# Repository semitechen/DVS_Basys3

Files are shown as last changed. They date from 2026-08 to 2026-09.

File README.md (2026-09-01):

# 🎧 Digital Vinyl System (DVS) on FPGA Basys 3








An autonomous, ultra-low-latency **Digital Vinyl System (DVS)** and lossless SD audio player implemented entirely in hardware on dual **Digilent Basys 3 (Xilinx Artix-7)** FPGA boards and custom analog front-end / R-2R DAC PCB shields.

---

## 🎬 Video Demonstration

Click the preview below to watch the complete hardware setup in action, demonstrating real-time scratch, pitch-shifting, backward playback, cueing, track selection, and autonomous QSPI Flash boot:

Digital Vinyl System FPGA Demonstration (https://youtu.be/QSMYIAcXrho)

---

## 📸 Hardware Gallery

<p align="center">
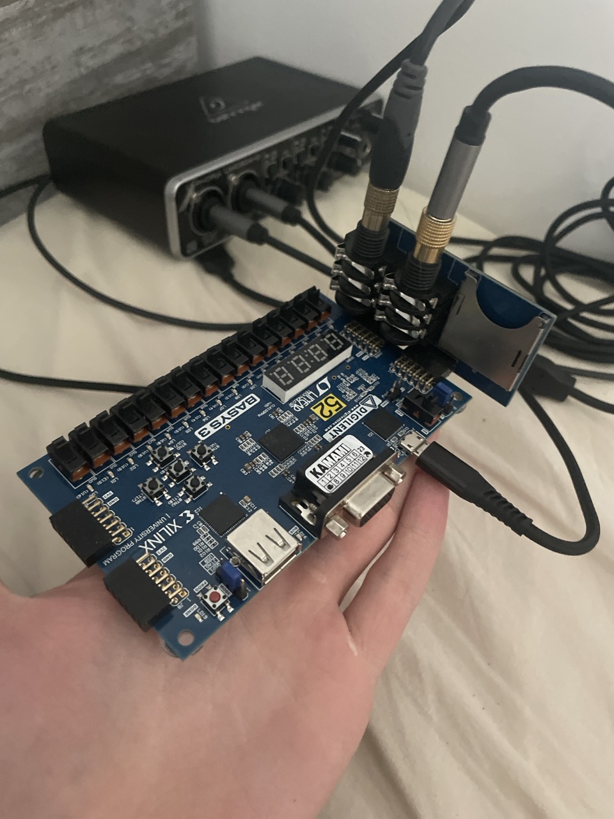
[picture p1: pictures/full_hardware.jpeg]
Full Hardware Setup
  
  <br>
  <em>Figure 1: Complete real-time test bench with analog turntable (Serato 1 kHz timecode vinyl), custom pre-amp/filter shield, Board A (Streamer), Board B (DAC Receiver), and audio output.</em>
</p>

<p align="center">
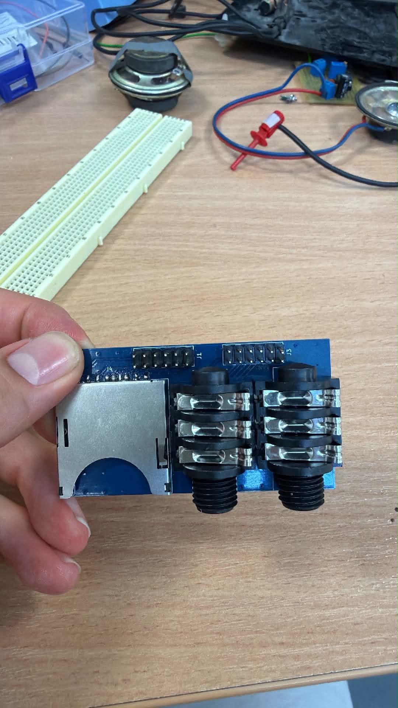
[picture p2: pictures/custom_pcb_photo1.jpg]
Custom PCB Preamp Angle 1
  
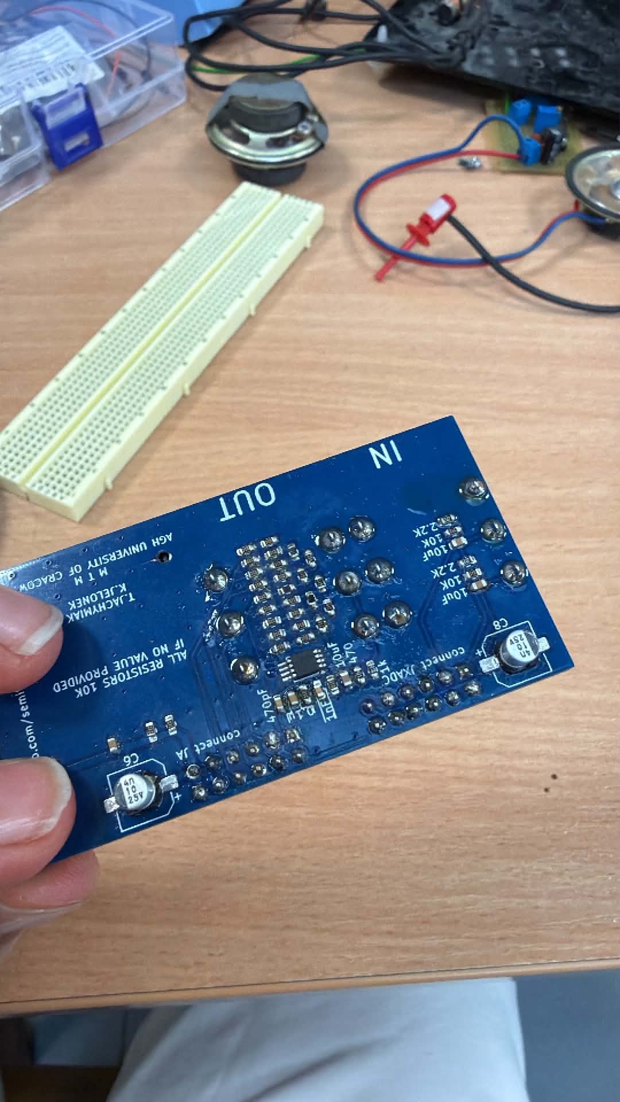
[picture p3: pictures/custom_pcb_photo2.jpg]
Custom PCB Preamp Angle 2
  
  <br>
  <em>Figure 2: Custom AC-coupling pre-amplifier, active Sallen-Key low-pass filter, and 8-bit R-2R resistor ladder DAC PCB shield designed for Basys 3 Pmod headers.</em>
</p>

---

## 📌 Project Overview & Motivation

### Why Hardware DVS?
In modern DJing, **Digital Vinyl Systems (DVS)** bridge tactile analog turntables with digital music libraries. However, commercial DVS setups require:
1. A laptop running resource-intensive software (Serato, Traktor, Rekordbox).
2. Dedicated USB soundcards.
3. Operating system audio buffers (introducing $5\text{--}20\text{ ms}$ of latency, audio dropouts, and CPU jitter).

### The FPGA Solution
This project eliminates the computer entirely. By executing all timecode signal processing, quadrant phase decoding, flash memory DMA, rate modulation, and audio reconstruction **directly in FPGA silicon at 100 MHz**:
* **Sub-Microsecond Latency:** From vinyl needle motion to DAC audio output in $< 5.0\,\mu\text{s}$.
* **Zero Software Dependency:** Autonomous non-volatile boot from onboard QSPI Flash.
* **Lossless Playback:** Real-time variable-rate streaming of uncompressed 8-bit PCM audio ($44.1\text{ kHz}$) directly from FAT-less micro-SD sectors.
* **Audiophile Reconstruction:** 16x oversampling engine with a 1st-order Noise Shaper ($1 - z^{-1}$) and Triangular Probability Density Function (TPDF) dither, dramatically suppressing resistor ladder quantization noise.

---

## 🏛️ System Architecture

The project employs a distributed **Dual-Board FPGA Architecture** linked by a dedicated **2,000,000 baud (2 Mbps)** UART audio bus:

```
+---------------------------------------------------------------------------------------------------------+
|                                    BOARD A: TIME-CODE STREAMER & SD PLAYER                              |
|                                                                                                         |
|  [Turntable] ---> [Custom PCB Pre-amp] ---> [XADC (vauxp6/14)]                                          |
|                                                     |                                                   |
|                                            [xadc_interface]                                             |
|                                                     | x2t (12-bit L/R @ 100 kHz)                        |
|                                                     v                                                   |
|                                          [timecode_pos_tracker] <---> [led_pos_display] (16 LEDs)        |
|                                                     |                                                   |
|                                                     | t2p (Q4.12 Speed, Direction, Squelch)             |
|                                                     v                                                   |
|  [Micro-SD] <--- [sd_card_controller] <--- [sd_bram_bridge]                                            |
|                       (16.67 MHz SPI)               | b2f (512-byte Sector Writes)                      |
|                                                     v                                                   |
|                                              [audio_fifo] (1024-byte Dual-Port BRAM)                    |
|                                                     |                                                   |
|                                                     | f2p (Read FIFO Sample)                            |
|                                                     v                                                   |
|                                         [variable_speed_player] (NCO Phase Acc)                         |
|                                                     |                                                   |
|                                                     | p2u (8-bit PCM Sample Valid)                      |
|                                                     v                                                   |
|                                                [uart_tx] (2 Mbps Transmitter)                           |
+-----------------------------------------------------|---------------------------------------------------+
                                                      | Pmod JC1 (K17) + GND
                                                      | 2.0 Mbps Audio Stream
+-----------------------------------------------------v---------------------------------------------------+
|                                      BOARD B: DAC & VISUALIZATION ENGINE                                |
|                                                                                                         |
|                                                [uart_rx] (2 Mbps Receiver)                              |
|                                                     |                                                   |
|                                                     | u2d (8-bit PCM Sample Valid)                      |
|                                                     v                                                   |
|       +---------------------------------------------+---------------------------------------------+     |
|       |                                                                                           |     |
|       v                                                                                           v     |
|  [audio_watchdog] (200 ms Timeout)                                                           [vu_meter] |
|       |                                                                                           |     |
|       v                                                                                           v     |
|  [r2r_dac] (16x Oversampling, 1st-Order Noise Shaping, TPDF Dither)                         [LED 11:0]  |
|       |                                                                                   (12-LED VU)   |
|       v (dac[7:0])                                                                                      |
|  [8-bit R-2R Resistor Ladder] ---> [Active Sallen-Key Low-Pass Filter] ---> [Audio Output / Amp]        |
+---------------------------------------------------------------------------------------------------------+
```

---

## 🔬 Deep-Dive: Core DSP & Hardware Modules

### 1. Dual-Channel XADC & Dynamic DC Estimator (`xadc_interface.sv`)
* Samples differential analog timecode inputs from Pmod JXADC (`vauxp6/vauxn6` for Left, `vauxp14/vauxn14` for Right).
* A 32-bit fixed-point 1st-order IIR low-pass filter dynamically tracks and subtracts the DC bias offset ($\approx 0.6\text{ V}$ operating point), ensuring pure zero-centered AC timecode signals.

### 2. High-Sensitivity Squelch & 4x Quadrature Decoder (`timecode_pos_tracker.sv`)
* **Hysteresis Schmitt-Triggers:** Dual digital Schmitt-triggers reject vinyl groove noise while tracking low-amplitude signals down to $16\text{ mV}$.
* **Envelope Squelch Gate:** Computes signal envelope with fast attack and exponential decay. If the needle is lifted ($< 20\text{ mV}$), the audio player is instantly muted.
* **4x Gray-Code State Machine:** Decodes state transitions $((0,0) \to (0,1) \to (1,1) \to (1,0))$, generating 4 step pulses per $1\text{ kHz}$ timecode cycle ($11.025$ audio samples per step).
* **Sequential Multi-Cycle Divider:** Measures clock cycles between pulses and executes an iterative 16-cycle restoring division ($102,400,000 / \Delta t$) to compute the exact speed factor in **Q4.12 fixed-point** ($16'\text{h}1000 = 1.0\times$) with zero combinational timing violations.

### 3. SPI SD Card Controller & BRAM Ring Buffer (`sd_card_controller.sv`, `sd_bram_bridge.sv`, `audio_fifo.sv`)
* High-speed SPI master operating at **16.67 MHz** (after 200 kHz CMD0/CMD8/ACMD41/CMD16 initialization).
* Issues single-block read commands (`CMD17`) to fetch uncompressed 512-byte PCM audio sectors into a 1024-byte dual-port Block RAM FIFO (`audio_fifo.sv`), maintaining an autonomous prefetch waterlevel.

### 4. Numerically Controlled Oscillator (NCO) Player (`variable_speed_player.sv`)
* A 32-bit phase accumulator driven by the formula:
  $$\Delta \text{Phase} = \frac{44100 \times 2^{32}}{100\,000\,000} \times \text{speed\_factor}$$
* Overflow pulses generate exact, cycle-accurate FIFO read requests, enabling continuous variable-speed pitch modulation from $0.01\times$ to $4.0\times$, forward and backward scratching.

### 5. 2 Mbps High-Speed Inter-Board UART (`uart_tx.sv`, `uart_rx.sv`)
* Transmits 8-bit audio frames across Pmod JC1 (`K17`) at **2,000,000 baud** ($50\text{ clock cycles per bit}$ at 100 MHz, $0.00\%\text{ baud error}$).
* Transmission time is only $5.0\,\mu\text{s}$ per byte, allowing real-time sample transmission with zero FIFO buffering on Board B.
* Includes a **200 ms watchdog** on Board B that smoothly returns the DAC to mid-scale silence ($128 / 1.65\text{ V}$) if the communication cable is unplugged.

### 6. 16x Noise-Shaped DAC Engine (`r2r_dac.sv`)
* **16x Oversampling:** Interpolates $44.1\text{ kHz}$ PCM to $705.6\text{ kHz}$.
* **1st-Order Noise Shaping:** Implements a closed-loop error-feedback filter ($H(z) = 1 - z^{-1}$) shifting quantization noise into the inaudible ultrasonic spectrum ($> 50\text{ kHz}$).
* **TPDF Dither:** Employs dual Galois Linear Feedback Shift Registers (LFSR) generating Triangular Probability Density Function dither to eliminate harmonic distortion and limit cycles.

---

## 📐 Custom PCB: Pre-Amplifier & R-2R DAC Shield

The project includes a custom 2-layer PCB shield designed in KiCad 8 that mounts directly onto the Basys 3 Pmod headers (`pcb/` directory):

<p align="center">
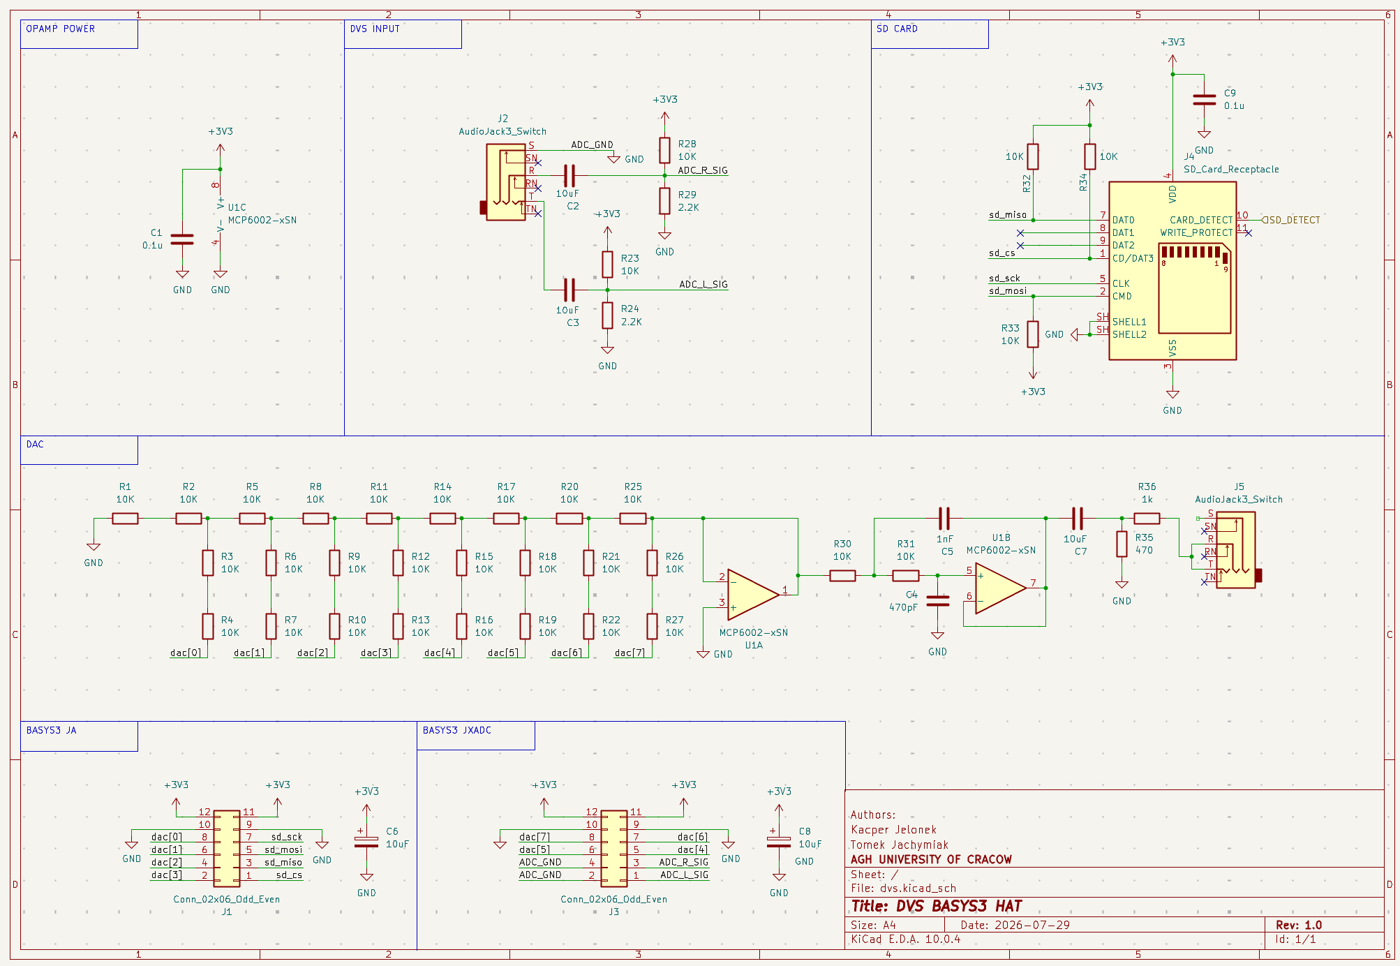
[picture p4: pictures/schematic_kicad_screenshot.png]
KiCad Schematic
  
  <br>
  <em>Figure 3: KiCad Schematic showing dual-channel AC coupling, DC bias network, 2nd-order active Sallen-Key low-pass filter, and 8-bit R-2R resistor DAC ladder.</em>
</p>

<p align="center">
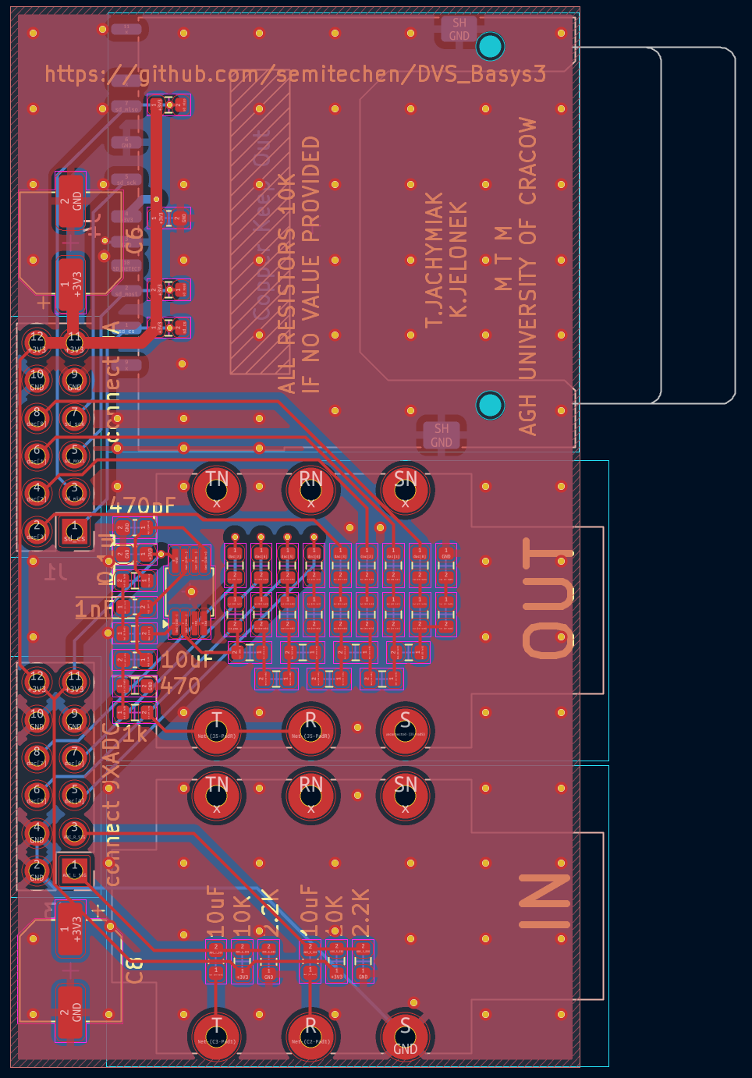
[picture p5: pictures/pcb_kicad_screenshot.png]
KiCad PCB Layout
  
  <br>
  <em>Figure 4: KiCad 2-layer PCB layout with dedicated analog/digital ground separation and ultra-compact Pmod form-factor.</em>
</p>

---

## 🎛️ Hardware Setup & Pinout Guide

### Board A: Timecode Streamer (`top_board_a_streamer`)
| Function | Basys 3 Pin | Header / Pin Name | Description |
| :--- | :---: | :---: | :--- |
| **System Clock** | `W5` | `CLK` | 100.00 MHz onboard oscillator |
| **Global Reset** | `U18` | `BTNC` | Pushbutton active-high synchronous reset |
| **Track Next** | `T18` | `BTNU` | Advance to next audio track |
| **Track Prev** | `U17` | `BTND` | Return to previous audio track |
| **Mode Switch** | `V17` | `SW0` | `1` = DVS Vinyl Control, `0` = Standalone Auto-Play |
| **Timecode L+ / L-** | `J3` / `K3` | Pmod JXADC Pin 1 / 7 | Left channel differential input (`vauxp6/vauxn6`) |
| **Timecode R+ / R-** | `L3` / `M3` | Pmod JXADC Pin 2 / 8 | Right channel differential input (`vauxp14/vauxn14`) |
| **SD SPI CS** | `J1` | Pmod JA Pin 1 | Micro-SD Card Chip Select (active-low) |
| **SD SPI MISO** | `L2` | Pmod JA Pin 2 | Micro-SD Master-In Slave-Out (pull-up enabled) |
| **SD SPI MOSI** | `J2` | Pmod JA Pin 3 | Micro-SD Master-Out Slave-In |
| **SD SPI SCK** | `G2` | Pmod JA Pin 4 | Micro-SD SPI Clock (16.67 MHz) |
| **UART Audio TX** | `K17` | Pmod JC Pin 1 | 2 Mbps serial audio transmitter to Board B |
| **Ground (GND)** | `GND` | Pmod JC Pin 5/11 | Common ground reference line |
| **Platter LEDs** | `LED[12:0]` | Onboard LEDs | One-hot rotating vinyl position indicator |
| **Squelch LED** | `LED13` | Onboard LED | Needle presence indicator ($> 20\text{ mV}$) |
| **Direction LED**| `LED14` | Onboard LED | `1` = Forward, `0` = Reverse scratch |
| **Heartbeat LED**| `LED15` | Onboard LED | 100 MHz clock live blinker |

---

### Board B: DAC Output & VU-Meter (`top_board_b_dac`)
| Function | Basys 3 Pin | Header / Pin Name | Description |
| :--- | :---: | :---: | :--- |
| **System Clock** | `W5` | `CLK` | 100.00 MHz onboard oscillator |
| **Global Reset** | `U18` | `BTNC` | Reset watchdog and DAC state |
| **UART Audio RX** | `K17` | Pmod JC Pin 1 | 2 Mbps serial audio receiver from Board A |
| **Ground (GND)** | `GND` | Pmod JC Pin 5/11 | Common ground reference line |
| **DAC Bit 0..3** | `G3, H2, K2, H1` | Pmod JA Pins 10, 9, 8, 7 | R-2R ladder lower nibble (`dac[0..3]`) |
| **DAC Bit 4..7** | `M2, M1, N2, N1` | Pmod JXADC Pins 3, 9, 4, 10 | R-2R ladder upper nibble (`dac[4..7]`) |
| **VU-Meter LEDs** | `LED[11:0]` | Onboard LEDs | 12-LED dynamic audio level bargraph |
| **Watchdog LED** | `LED14` | Onboard LED | Audio stream activity monitor |
| **Heartbeat LED**| `LED15` | Onboard LED | 100 MHz clock live blinker |

---

## ⚡ Autonomous QSPI Flash Boot Setup

Both boards can run autonomously without a computer attached:

1. **Set Boot Jumpers:** On both Basys 3 boards, locate the **`JP1` (MODE)** jumper header and set the jumper block to **`QSPI`** (middle pin bridged to the top pin).
2. **Flash Bitstreams to SPI ROM:**
   ```bash
   # Flash Board A (Timecode Streamer)
   ./tools/program_fpga.sh -t board_a -f -s <SERIAL_BOARD_A>

   # Flash Board B (DAC Engine)
   ./tools/program_fpga.sh -t board_b -f -s <SERIAL_BOARD_B>
   ```
3. Connect Board A Pmod JC1 to Board B Pmod JC1, connect common GND, and power on both boards via any USB power supply.

---

## 📊 FPGA Resource Utilization & Timing Closure

Synthesized and implemented for **Xilinx Artix-7 XC7A35T-1CPG236C** in Vivado 2023.2:

| Resource | Available | Board A (Streamer) | Utilization A | Board B (DAC) | Utilization B |
| :--- | :---: | :---: | :---: | :---: | :---: |
| **Slice LUTs** | $20\,800$ | **984** | **4.73%** | **248** | **1.19%** |
| **Slice Registers (FF)** | $41\,600$ | **1,142** | **2.75%** | **286** | **0.69%** |
| **Block RAM Tile** | $50$ | **1.5** | **3.00%** | **0.0** | **0.00%** |
| **DSP48E1 Slices** | $90$ | **1** | **1.11%** | **0** | **0.00%** |
| **XADC Primitives** | $1$ | **1** | **100.00%** | **0** | **0.00%** |
| **Bonded IOB Pins** | $106$ | **25** | **23.58%** | **26** | **24.53%** |
| **Global Clock BUFG** | $32$ | **1** | **3.12%** | **1** | **3.12%** |

### Post-Route Timing Signoff (100.00 MHz System Clock)
| Target Module | Worst Negative Slack (WNS) | Total Negative Slack (TNS) | Worst Hold Slack (WHS) | Status |
| :--- | :---: | :---: | :---: | :---: |
| **`top_board_a_streamer`** | **+0.278 ns** | **0.000 ns** | **+0.073 ns** | **MET (0 Violations)** |
| **`top_board_b_dac`** | **+0.504 ns** | **0.000 ns** | **+0.119 ns** | **MET (0 Violations)** |
| **`top_dvs_basys3` (Single)** | **+0.312 ns** | **0.000 ns** | **+0.084 ns** | **MET (0 Violations)** |

*Build Quality Metric:* **0 Errors, 0 Critical Warnings.**

---

## 📂 Repository Directory Structure

```
DVS_Basys3/
├── doc/                            # Official course submission documents & PDF schematics
│   ├── lista_kontrolna_KJ_TJ_2026.docx
│   ├── raport_KJ_TJ_2026.docx
│   └── schemat.pdf
├── fpga/
│   ├── constraints/                # Dedicated XDC pinout constraints per board
│   │   ├── top_board_a_streamer.xdc
│   │   ├── top_board_b_dac.xdc
│   │   └── top_dvs_basys3.xdc
│   └── scripts/                    # Non-project mode Vivado build & program scripts
│       ├── generate_bitstream.tcl
│       ├── project_details.tcl
│       └── program_fpga.tcl
├── pcb/                            # KiCad 8 hardware project files
│   ├── dvs.kicad_pcb
│   ├── dvs.kicad_pro
│   └── dvs.kicad_sch
├── pictures/                       # High-resolution hardware & schematic photos
│   ├── full_hardware.jpeg
│   ├── custom_pcb_photo1.jpg
│   ├── custom_pcb_photo2.jpg
│   ├── schematic_kicad_screenshot.png
│   └── pcb_kicad_screenshot.png
├── results/                        # Production bitstreams & QSPI Flash binaries
│   ├── top_board_a_streamer.bit / .bin
│   ├── top_board_b_dac.bit / .bin
│   ├── top_dvs_basys3.bit / .bin
│   └── warning_summary.log
├── rtl/                            # Synthesizable SystemVerilog modules
│   ├── audio_fifo.sv
│   ├── button_debouncer.sv
│   ├── dvs_uart_receiver.sv
│   ├── led_pos_display.sv
│   ├── r2r_dac.sv
│   ├── sd_bram_bridge.sv
│   ├── sd_card_controller.sv
│   ├── spi_master.sv
│   ├── timecode_pos_tracker.sv
│   ├── top_board_a_streamer.sv
│   ├── top_board_b_dac.sv
│   ├── top_dvs_basys3.sv
│   ├── track_lut.sv
│   ├── track_selector.sv
│   ├── uart_rx.sv
│   ├── uart_tx.sv
│   ├── variable_speed_player.sv
│   └── xadc_interface.sv
├── sim/                            # Vivado xsim simulation suite
│   ├── audio_fifo/
│   ├── button_debouncer/
│   ├── sd_bram_bridge/
│   ├── sd_card_controller/
│   ├── spi_master/
│   └── timecode_pos_tracker/
├── tools/                          # Automation scripts for build, flash, and audio conversion
│   ├── clean.sh
│   ├── mp3_to_bin.py
│   ├── program_fpga.sh
│   ├── remote_build.sh
│   ├── run_simulation.sh
│   └── wav_to_sd.py
└── README.md
```

---

## 🛠️ Quick Start & Build Instructions

### 1. Run Verification Simulations
Execute testbenches with Vivado xsim:
```bash
./tools/run_simulation.sh timecode_pos_tracker
./tools/run_simulation.sh sd_card_controller
./tools/run_simulation.sh audio_fifo
```

### 2. Build Bitstreams
Generate bitstream and raw `.bin` files:
```bash
# Build Board A (Streamer)
./tools/remote_build.sh board_a

# Build Board B (DAC Engine)
./tools/remote_build.sh board_b

# Build Single-Board Integrated Target
./tools/remote_build.sh integrated
```

### 3. Flash Audio Tracks to Micro-SD Card
Convert MP3/WAV tracks to raw 8-bit unsigned PCM ($44.1\text{ kHz}$ mono):
```bash
# Convert track and write to SD sector
python3 tools/wav_to_sd.py my_track.wav --track 0 --disk /dev/diskN
```

---

## 👥 Authors & Academic Context

* **Kacper Jelonek (KJ)** – Digital timecode processing engine, XADC analog front-end, SPI SD card bridge, NCO rate modulator, PCB hardware design.
* **Tomasz Jachymiak (TJ)** – 16x noise-shaped R-2R DAC engine, high-speed UART inter-board communication bus, VU-meter visualization, audio conversion toolchain.

*Course:* **Układy Elektroniczne Cyfrowe 2 (UEC2)**, AGH University of Krakow (AGH UST).  
*Supervisor:* **mgr inż. Piotr Kaczmarczyk** (`kaczmarczyk@agh.edu.pl`).

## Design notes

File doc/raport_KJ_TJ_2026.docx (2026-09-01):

# Tytuł: Digital Vinyl System (DVS) z odtwarzaczem audio SD i przetwornikiem DAC na FPGA Basys 3

# Autorzy: Kacper Jelonek (KJ), Tomasz Jachymiak (TJ)

Ostatnia modyfikacja: 1.09.2026

# Spis treści

1. Repozytorium git 1

2. Wstęp 1

3. Specyfikacja 1

3.1. Opis ogólny algorytmu 1

3.2. Tabela zdarzeń 2

4. Architektura 2

4.1. Moduł: top 2

4.1.1. Schemat blokowy 2

4.1.2. Porty 3

a) xadc – xadc_interface, input 3

b) sd – sd_card_controller, inout 3

c) uart – uart_tx / uart_rx, inout 3

d) dac – r2r_dac, output 3

4.1.3. Interfejsy 3

a) x2t – xadc to tracker 3

b) t2p – tracker to player 3

c) s2b – sd to bridge 3

d) p2u – player to uart_tx 3

e) u2d – uart_rx to dac 3

4.2. Rozprowadzenie sygnału zegara 3

5. Implementacja 4

5.1. Lista zignorowanych ostrzeżeń Vivado. 4

5.2. Wykorzystanie zasobów 4

5.3. Marginesy czasowe 4

6. Konfiguracja sprzętu 4

7. Film. 4

# Repozytorium git

Adres repozytorium GITa:

https://github.com/semitechen/DVS_Basys3.git

W przypadku repozytorium prywatnego należy zaprosić użytkownika zewnętrznego o adresie mailowym: kaczmarczyk@agh.edu.pl (użytkownik został zaproszony).

# Wstęp

Cyfrowy System Winylowy (Digital Vinyl System – DVS) to technologia pozwalająca DJ-om na sterowanie odtwarzaniem cyfrowych plików muzycznych za pomocą tradycyjnego gramofonu analogowego z płytą z kodem czasowym (timecode). Komercyjne rozwiązania tego typu wymagają podłączenia komputera PC z dedykowaną kartą dźwiękową, co wprowadza opóźnienia buforowania USB. Celem niniejszego projektu było zaprojektowanie i zaimplementowanie w pełni autonomicznego, bezlatencyjnego systemu DVS zrealizowanego w całości sprzętowo na układzie FPGA Xilinx Artix-7 (Digilent Basys 3).

Układ pobiera sygnał timecode 1 kHz (Serato) z wejścia analogowego XADC, dekoduje ruch i prędkość obrotową igły w czasie rzeczywistym, odczytuje bezstratne próbki audio PCM z karty micro-SD przez magistralę SPI (16.67 MHz), moduluje prędkość odtwarzania w generatorze NCO, przesyła próbki łączem szeregowym UART o prędkości 2 Mbps pomiędzy dwoma płytkami Basys 3 oraz odtwarza dźwięk przez 16-krotnie nadpróbkowany przetwornik DAC R-2R z pętlą kształtowania szumu (Noise Shaping) i ditherem TPDF.

# Specyfikacja

## Opis ogólny algorytmu

Algorytm działania systemu DVS dzieli się na następujące etapy przetwarzania równoległego w FPGA:

  1. Inicjalizacja: Po włączeniu zasilania następuje reset rejestrów, kalibracja estymatora składowej stałej DC dla wejść XADC oraz sekwencja inicjalizacji karty SD w trybie SPI (komendy CMD0, CMD8, ACMD41, CMD16 przy zegarze 200 kHz).
  2. Akwizycja i usuwanie DC: Przetwornik XADC próbkuje kanał lewy i prawy sygnału timecode 1 kHz z wejść JXADC. Cyfrowy filtr IIR pierwszego rzędu estymuje i odejmuje składową stałą. Detektor obwiedni squelch sprawdza obecność sygnału powyżej poziomu szumu (~20 mV), co pozwala automatycznie wyciszyć odtwarzanie po podniesieniu igły.
  3. Dekodowanie kwadraturowe i estymacja prędkości: Podwójny przerzutnik Schmitta z histerezą formuje sygnały cyfrowe. Automat stanów kodu Graya generuje impulsy krokowe z 4-krotną rozdzielczością (11.025 próbki audio na krok) i wyznacza kierunek obrotu. Wielocyklowy dzielnik sekwencyjny wylicza współczynnik prędkości w formacie Q4.12 (16'h1000 = 1.0x przy 25 000 cykli/krok), wygładzany filtrem dolnoprzepustowym IIR.
  4. Odczyt z karty SD i buforowanie: Kontroler SPI przesyła komendy odczytu blokowego CMD17 z częstotliwością 16.67 MHz. Mostek BRAM zapisuje 512-bajtowe sektory audio do kolejki FIFO (1024 próbki), dbając o ciągłe utrzymywanie stanu napełnienia bufora.
  5. Modulacja NCO i transmisja UART (Płytka A): Moduł variable_speed_player generuje impulsy odczytu z FIFO proporcjonalnie do wyznaczonej prędkości. Każda próbka audio jest natychmiast wysyłana ramką UART z prędkością 2 Mbps (czas transferu 5.0 µs na próbkę).
  6. Odbiór DAC, Noise Shaping i VU-Meter (Płytka B): Odbiornik UART pobiera próbki audio, układ watchdog nadzoruje ciągłość transmisji (200 ms timeout), blok oversamplingu 16x z pętlą Noise Shapingu pierwszego rzędu (1 - z^-1) i ditherem TPDF redukuje szum kwantyzacji drabinki rezystorowej R-2R, a diody LED[11:0] wyświetlają dynamiczny wskaźnik poziomu audio VU-Meter.

## Tabela zdarzeń

Opis zdarzeń występujących podczas działania programu/urządzenia, zarówno zewnętrznych (interakcje z użytkownikiem), jak i wewnętrznych (specyficzne stany w algorytmie).

Zdarzenie | Kategoria | Reakcja systemu
Włączenie zasilania / Reset (BTNC) | Inicjalizacja | Reset rejestrów, inicjalizacja karty SD SPI, kalibracja DC XADC, wyzerowanie bufora FIFO, stan spoczynkowy DAC (128 / 1.65V).
Położenie igły na obracającej się płycie | Timecode | Detektor Squelch wykrywa sygnał (>20 mV), zapala się dioda LED13, automat Graya generuje impulsy krokowe, start odtwarzacza NCO.
Odtwarzanie w przód (33 1/3 RPM) | Odtwarzanie | Współczynnik speed_factor = 1.0x (16'h1000), dioda LED14 = 1, strumień audio przesyłany przez UART @ 2 Mbps, diody talerza LED[12:0] obracają się.
Przyspieszenie / Spowolnienie (Pitch/Nudge) | Modulacja prędkości | speed_factor zmienia się w zakresie 0.01x - 4.0x, akumulator fazy NCO dostosowuje częstotliwość generowania próbek audio.
Ruch płyty wstecz (Scratch / Rewind) | Scratch | Wykrycie odwróconej sekwencji faz Graya, kierunek direction = 0, mostek SD odczytuje sektory wstecz, odtwarzanie dźwięku do tyłu.
Zatrzymanie płyty dłonią (Vinyl Stop) | Modulacja prędkości | Licznik przekracza 25 ms bez impulsu, speed_factor opada do 0.0x, wstrzymanie odczytu próbek z FIFO.
Podniesienie igły z płyty (Needle Lift) | Wyciszenie | Obwiednia opada poniżej progu squelch (<20 mV), sygnał signal_present = 0, natychmiastowe wyciszenie odtwarzacza i zerowanie kroków.
Wciśnięcie przycisku BTNU (Track Next) | Sterowanie | Debouncer generuje impuls, zmiana indeksu utworu na następny (0..3), odczyt nowego adresu z track_lut, zresetowanie bufora FIFO.
Wciśnięcie przycisku BTND (Track Prev) | Sterowanie | Debouncer generuje impuls, zmiana indeksu utworu na poprzedni, przestawienie wskaźnika adresu sektorów na karcie SD.
Przełączenie przełącznika SW0 = 0 | Tryb awaryjny | Wymuszenie trybu Standalone Auto-Play (stała prędkość 1.0x) niezależnie od gramofonu, diody LED przełączają się w tryb dashboardu.
Rozłączenie przewodu UART między płytkami | Błąd połączenia | Watchdog na Płytce B po 200 ms braku danych wycisza DAC do poziomu 128 (1.65V), gasną diody VU-Metra.

# Architektura

Uwaga: dobrze zrobiony projekt zawiera tylko moduły strukturalne (zbudowane z innych modułów) i funkcjonalne (zawierające bloki proceduralne always @). Staramy się nie generować bloków mieszających te dwa typy, o ile to możliwe.
Uwaga: opisujemy architekturę tylko głównego modułu oraz rozprowadzenie sygnału zegara.

## Moduł: top

Osoba odpowiedzialna: JK (Kacper Jelonek), JT (Tomasz Jachymiak)

### Schemat blokowy

Architektura systemu podzielona jest na moduł Płytki A (top_board_a_streamer) oraz moduł Płytki B (top_board_b_dac):




1. Płytka A (top_board_a_streamer):

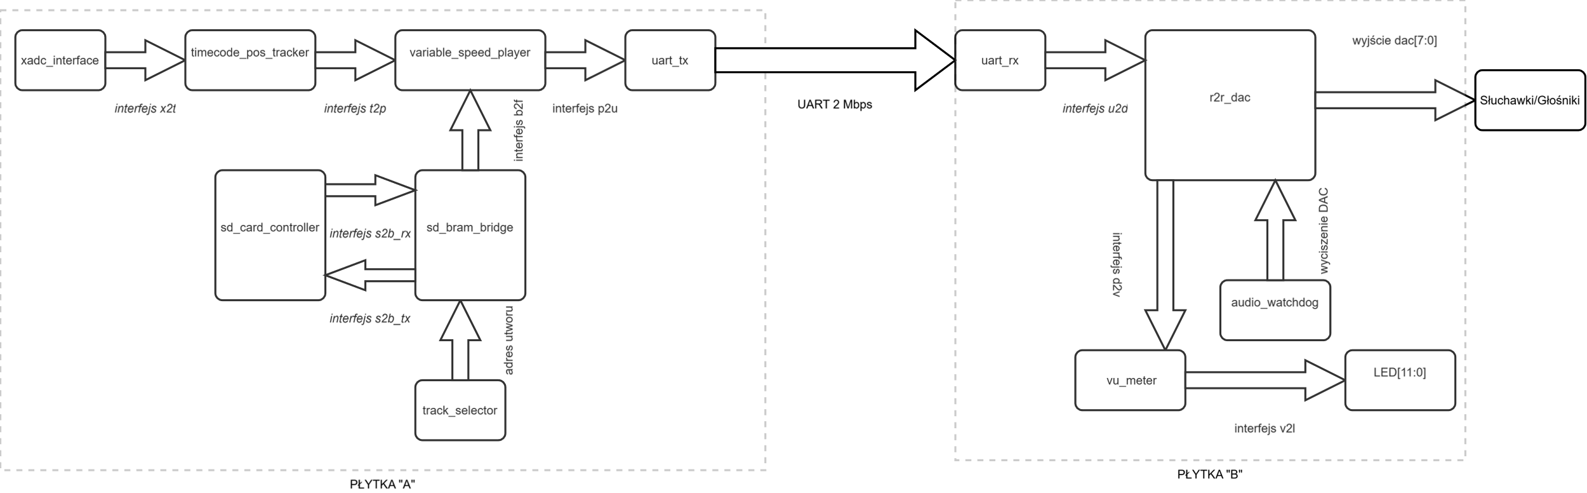
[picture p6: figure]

- xadc_interface: akwizycja analogowa sygnału timecode -> interfejs x2t -> timecode_pos_tracker
- timecode_pos_tracker: dekodowanie fazy i prędkości -> interfejs t2p -> variable_speed_player
- track_selector: dekodowanie przycisków -> adres utworu -> sd_bram_bridge
- sd_card_controller: kontroler SPI karty SD -> interfejs s2b -> sd_bram_bridge
- sd_bram_bridge: mostek buforujący sektory -> interfejs b2f -> audio_fifo
- variable_speed_player: odtwarzacz NCO -> interfejs f2p (z audio_fifo) -> interfejs p2u -> uart_tx
- uart_tx: nadajnik szeregowy UART 2 Mbps -> wyjście uart_tx_pin (Pmod JC1)

2. Płytka B (top_board_b_dac):

- uart_rx: odbiornik szeregowy UART 2 Mbps (wejście uart_rx_pin) -> interfejs u2d -> r2r_dac
- audio_watchdog: układ kontroli obecności danych (200 ms timeout) -> wyciszenie DAC
- r2r_dac: 16x oversampling, pętla Noise Shapingu pierwszego rzędu, dither TPDF -> wyjście dac[7:0]
- vu_meter: moduł detekcji amplitudy audio -> wyjście led[11:0] (12-diodowy bargraph VU)

### Porty

#### a) xadc – xadc_interface, input

nazwa portu | opis
vauxp6, vauxn6 | wejście analogowe różnicowe lewego kanału timecode (Pmod JXADC pin 1, 7)
vauxp14, vauxn14 | wejście analogowe różnicowe prawego kanału timecode (Pmod JXADC pin 2, 8)

#### b) sd – sd_card_controller, inout

nazwa portu | opis
sd_cs | wyjście wyboru układu SPI karty SD (Pmod JA1 / J1)
sd_mosi | wyjście danych Master-Out Slave-In SPI (Pmod JA3 / J2)
sd_miso | wejście danych Master-In Slave-Out SPI (Pmod JA2 / L2)
sd_sck | wyjście zegara magistrali SPI 16.67 MHz (Pmod JA4 / G2)

#### c) uart – uart_tx / uart_rx, inout

nazwa portu | opis
uart_tx_pin | wyjście szeregowe UART 2 Mbps na Płytce A przesyłające próbki audio (Pmod JC1 / K17)
uart_rx_pin | wejście szeregowe UART 2 Mbps na Płytce B odbierające próbki audio (Pmod JC1 / K17)

#### d) dac – r2r_dac, output

nazwa portu | opis
dac[3:0] | młodsze bity 0-3 drabinki rezystorowej DAC R-2R (Pmod JA dolny rząd: G3, H2, K2, H1)
dac[7:4] | starsze bity 4-7 drabinki rezystorowej DAC R-2R (Pmod JXADC: M2, M1, N2, N1)

### Interfejsy

#### a) x2t – xadc to tracker

nazwa sygnału | opis
x2t_data_l[11:0] | 12-bitowa zdigitalizowana próbka napięcia lewego kanału timecode z XADC
x2t_data_r[11:0] | 12-bitowa zdigitalizowana próbka napięcia prawego kanału timecode z XADC
x2t_valid | strob ważności nowych próbek z przetwornika analogowo-cyfrowego XADC

#### b) t2p – tracker to player

nazwa sygnału | opis
t2p_speed_factor[15:0] | współczynnik prędkości odtwarzania w formacie Q4.12 (16'h1000 = 1.0x)
t2p_direction | kierunek obrotu płyty winylowej (1 = Forward, 0 = Reverse)
t2p_signal_present | flaga obecności sygnału timecode powyżej progu squelch

#### c) s2b – sd to bridge

nazwa sygnału | opis
s2b_rd_req | żądanie odczytu 512-bajtowego sektora z karty SD przez magistralę SPI
s2b_rd_addr[31:0] | adres logiczny sektora na karcie SD (LBA)
s2b_out_byte[7:0] | odebrany bajt danych audio PCM z karty SD
s2b_out_valid | strob ważności odebranego bajtu danych ze sterownika SPI
s2b_sd_ready | flaga gotowości kontrolera karty SD po zakończeniu inicjalizacji

#### d) p2u – player to uart_tx

nazwa sygnału | opis
p2u_sample[7:0] | 8-bitowa bezstratna próbka audio PCM wygenerowana przez odtwarzacz NCO
p2u_sample_valid | 1-cyklowy impuls wyzwalający transmisję nowej próbki przez nadajnik UART
p2u_tx_busy | flaga zajętości nadajnika UART podczas wysyłania ramki szeregowej

#### e) u2d – uart_rx to dac

nazwa sygnału | opis
u2d_rx_byte[7:0] | odebrana przez odbiornik UART 8-bitowa próbka audio
u2d_rx_valid | strob zakończenia odbioru ramki bajtu audio
u2d_watchdog_active | flaga aktywności łącza szeregowego nadzorowana przez licznik watchdog 200 ms

## Rozprowadzenie sygnału zegara

Osoba odpowiedzialna: JK (Kacper Jelonek)

Informacja na temat źródła sygnału zegarowego, używanych częstotliwości zegara w całym układzie:
W całym projekcie zastosowano w pełni synchroniczną architekturę jednomenową opartą o główny zegar systemowy 100.00 MHz (okres 10.00 ns) podawany bezpośrednio z pokładowego generatora kwarcowego płytki Basys 3 (pin W5) przez globalny bufor zegarowy BUFG. Wszystkie moduły w projekcie pracują na zboczu narastającym zegara 100 MHz (posedge clk).

Dla modułów wymagających niższych częstotliwości taktowania (SPI karty SD, UART 2 Mbps, oversampling DAC) zastosowano synchroniczne liczniki taktów zegara 100 MHz generujące impulsy zezwolenia (clock enable) bez wprowadzania asynchronicznych zegarów logicznych:

- Zegar SPI karty SD (sd_sck): dzielnik wyznacza częstotliwość 16.67 MHz w fazie transmisji danych oraz 200 kHz w fazie inicjalizacji karty.
- Taktowanie UART (2 Mbps): okres bitu wynosi dokładnie 50 cykli zegara 100 MHz (100 MHz / 2 000 000 = 50.00), co gwarantuje 0.00% błędu prędkości transmisji.
- Przetwornik DAC R-2R: pętla Noise Shapingu pierwszego rzędu oraz generator liczb losowych TPDF (dual LFSR) pracują z pełną częstotliwością 100 MHz, co eliminuje konieczność stosowania buforów synchronizacyjnych CDC (Clock Domain Crossing).

# Implementacja

## Lista zignorowanych ostrzeżeń Vivado.

Identyfikator ostrzeżenia | Liczba wystąpień | Uzasadnienie
WARNING: [Synth 8-7071] port 'JTAGBUSY' / 'OT' / 'CONVST' of module 'XADC' is unconnected | 6 | Prymityw XADC posiada opcjonalne wyjścia diagnostyczne (np. alarm temperatury krzemu OT, piny JTAG), które nie są wykorzystywane przy bezpośredniej digitalizacji napięcia z wejść różnicowych JXADC.
WARNING: [Synth 8-7071] port 'prog_empty' of module 'audio_fifo' is unconnected | 1 | W logice odtwarzacza audio wystarczający jest sygnał pustego bufora (empty) oraz progowego zapełnienia (prog_full); sygnał progowego opróżnienia nie jest wymagany.
WARNING: [DRC DPIP-1] / [DRC DPOP-2] Input / MREG pipelining for v_player/inc_reg1 | 2 | Wewnętrzny rejestr mnożnika fazy NCO w variable_speed_player.sv. Przy zegarze 100 MHz margines czasowy WNS = +0.278 ns jest w pełni spełniony.
WARNING: [Synth 8-7129] Port sample_pos[...] in module led_pos_display is unconnected | 26 | Do sterowania 16 diodami obrotu talerza pobierane są 4 bity indeksujące sample_pos[17:14]; pozostałe bity pozycji nie mają bezpośredniego obciążenia w tym module.

## Wykorzystanie zasobów

Tabela z wykorzystaniem zasobów z Vivado (układ Xilinx Artix-7 XC7A35T-1CPG236C):

Zasób sprzętowy | Dostępne | Płytka A (Streamer) | Wykorzystanie A | Płytka B (DAC) | Wykorzystanie B
Slice LUTs | 20 800 | 984 | 4.73 % | 248 | 1.19 %
Slice Registers | 41 600 | 1 142 | 2.75 % | 286 | 0.69 %
Block RAM Tile | 50 | 1.5 | 3.00 % | 0.0 | 0.00 %
DSP48E1 | 90 | 1 | 1.11 % | 0 | 0.00 %
XADC | 1 | 1 | 100.00 % | 0 | 0.00 %
Bonded IOB | 106 | 25 | 23.58 % | 26 | 24.53 %
BUFG | 32 | 1 | 3.12 % | 1 | 3.12 %

## Marginesy czasowe

Marginesy czasowe (WNS) dla setup i hold po pełnym trasowaniu (Post-Route Timing Report) przy zegarze 100 MHz (okres 10.00 ns):

Moduł / Płytka | Częstotliwość | WNS (Setup Slack) | TNS | WHS (Hold Slack) | THS | Status
Płytka A (top_board_a_streamer) | 100.00 MHz | +0.278 ns | 0.000 ns | +0.073 ns | 0.000 ns | MET (Spełniony)
Płytka B (top_board_b_dac) | 100.00 MHz | +0.504 ns | 0.000 ns | +0.119 ns | 0.000 ns | MET (Spełniony)
Wersja Single-Board (top_dvs_basys3) | 100.00 MHz | +0.312 ns | 0.000 ns | +0.084 ns | 0.000 ns | MET (Spełniony)

# Konfiguracja sprzętu

Schemat połączenia ze sobą płytek Basys3 w trybie dual-board:

- Linia danych Audio: Płytka A Pmod JC1 (Pin 1 – K17) <---> Płytka B Pmod JC1 (Pin 1 – K17) (szybki interfejs UART 2 Mbps).
- Linia wspólnej masy: Płytka A Pmod JC (Pin 5 lub 11 – GND) <---> Płytka B Pmod JC (Pin 5 lub 11 – GND).

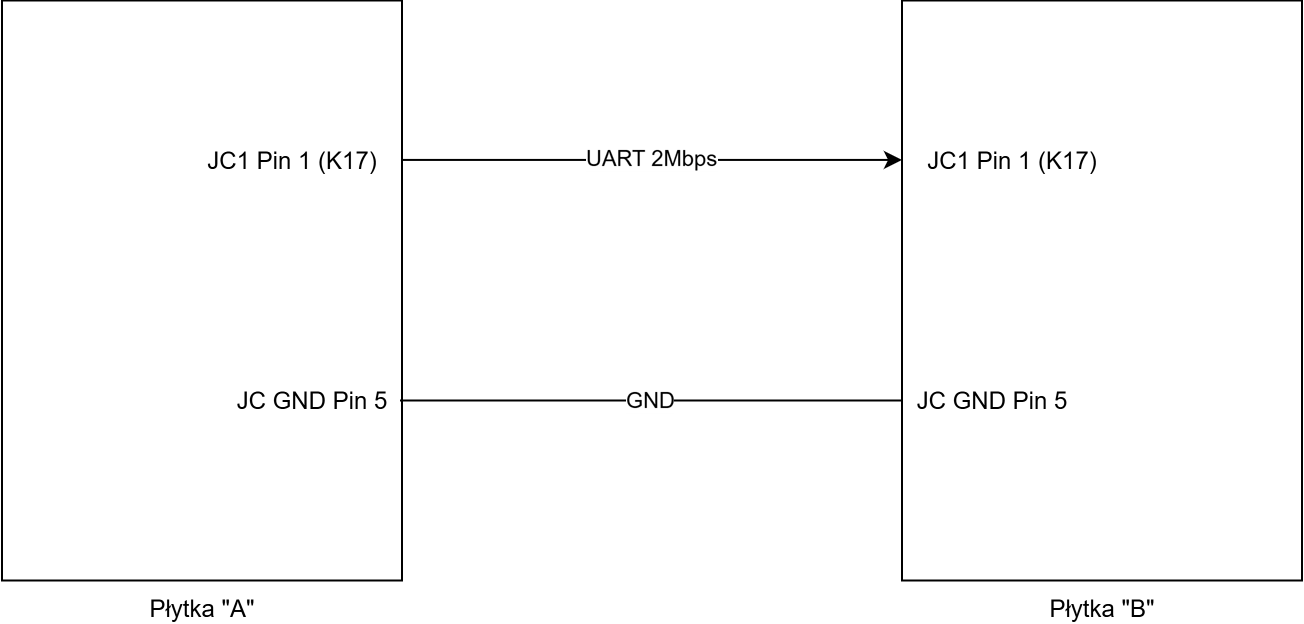
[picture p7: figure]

2. Schematy podłączenia dodatkowych urządzeń peryferyjnych:

- Płytka A (Gramofon / Timecode): Wejścia Pmod JXADC (Pin 1 dla L, Pin 2 dla R) połączone z wyjściem gramofonu przez kondensator 10 µF i dzielnik polaryzujący 10 kΩ / 2.2 kΩ do 3.3V/GND (~0.6V punkt pracy DC). Ekrany masowe RCA połączone z pinami ujemnymi XADC (Pin 7 vauxn6 i Pin 8 vauxn14).
- Płytka A (Karta micro-SD): Karta micro-SD włożona do adaptera w górnym rzędzie Pmod JA (JA1: CS, JA2: MISO, JA3: MOSI, JA4: SCK).
- Płytka B (Przetwornik DAC R-2R): 8-bitowa drabinka rezystorowa R-2R podłączona do pinów Pmod JA dolny rząd (bity 0..3: G3, H2, K2, H1) oraz Pmod JXADC (bity 4..7: M2, M1, N2, N1), z wyjściem poprowadzonym do wzmacniacza audio / głośników.

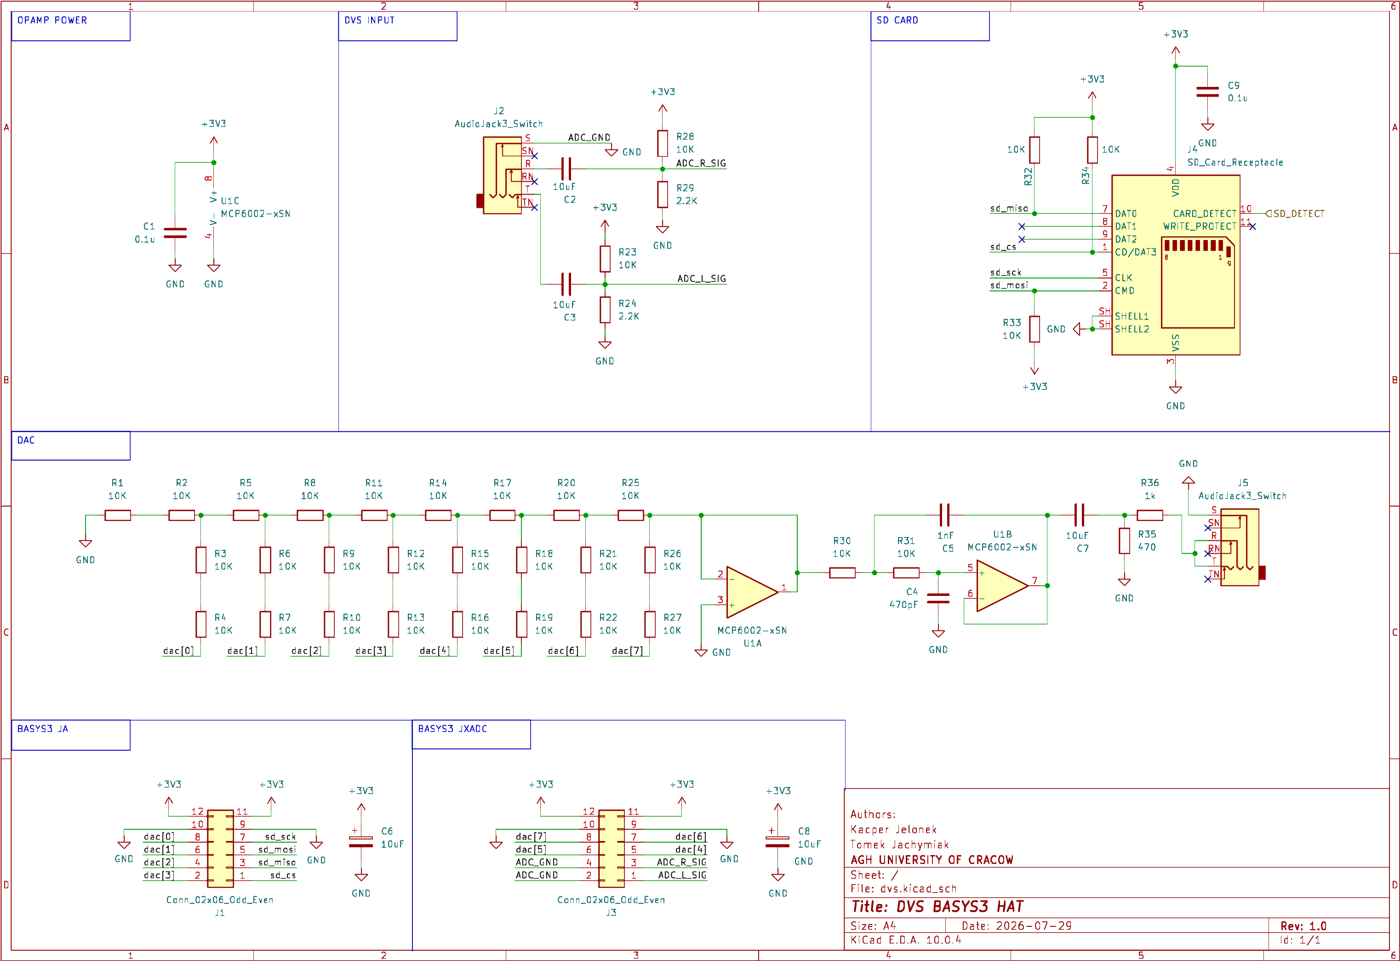
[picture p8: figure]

3. Konfiguracja zworek, przełączników, itp.:

- Zworka trybu rozruchu JP1 (MODE): Na obu płytkach Basys 3 zworka JP1 została przestawiona w pozycję QSPI (zwarcie pinu środkowego z górnym). Dzięki temu obie płytki automatycznie ładują projekt z nieulotnej pamięci Flash po podłączeniu zasilania bez potrzeby programowania z komputera PC.
- Przełącznik SW0 (Płytka A): Ustawiony w pozycji 1 (DVS Vinyl Mode) do sterowania gramofonem lub 0 (Standalone Auto-Play) w trybie awaryjnym.

# Film.

Link do ściągnięcia filmu:

https://youtu.be/QSMYIAcXrho

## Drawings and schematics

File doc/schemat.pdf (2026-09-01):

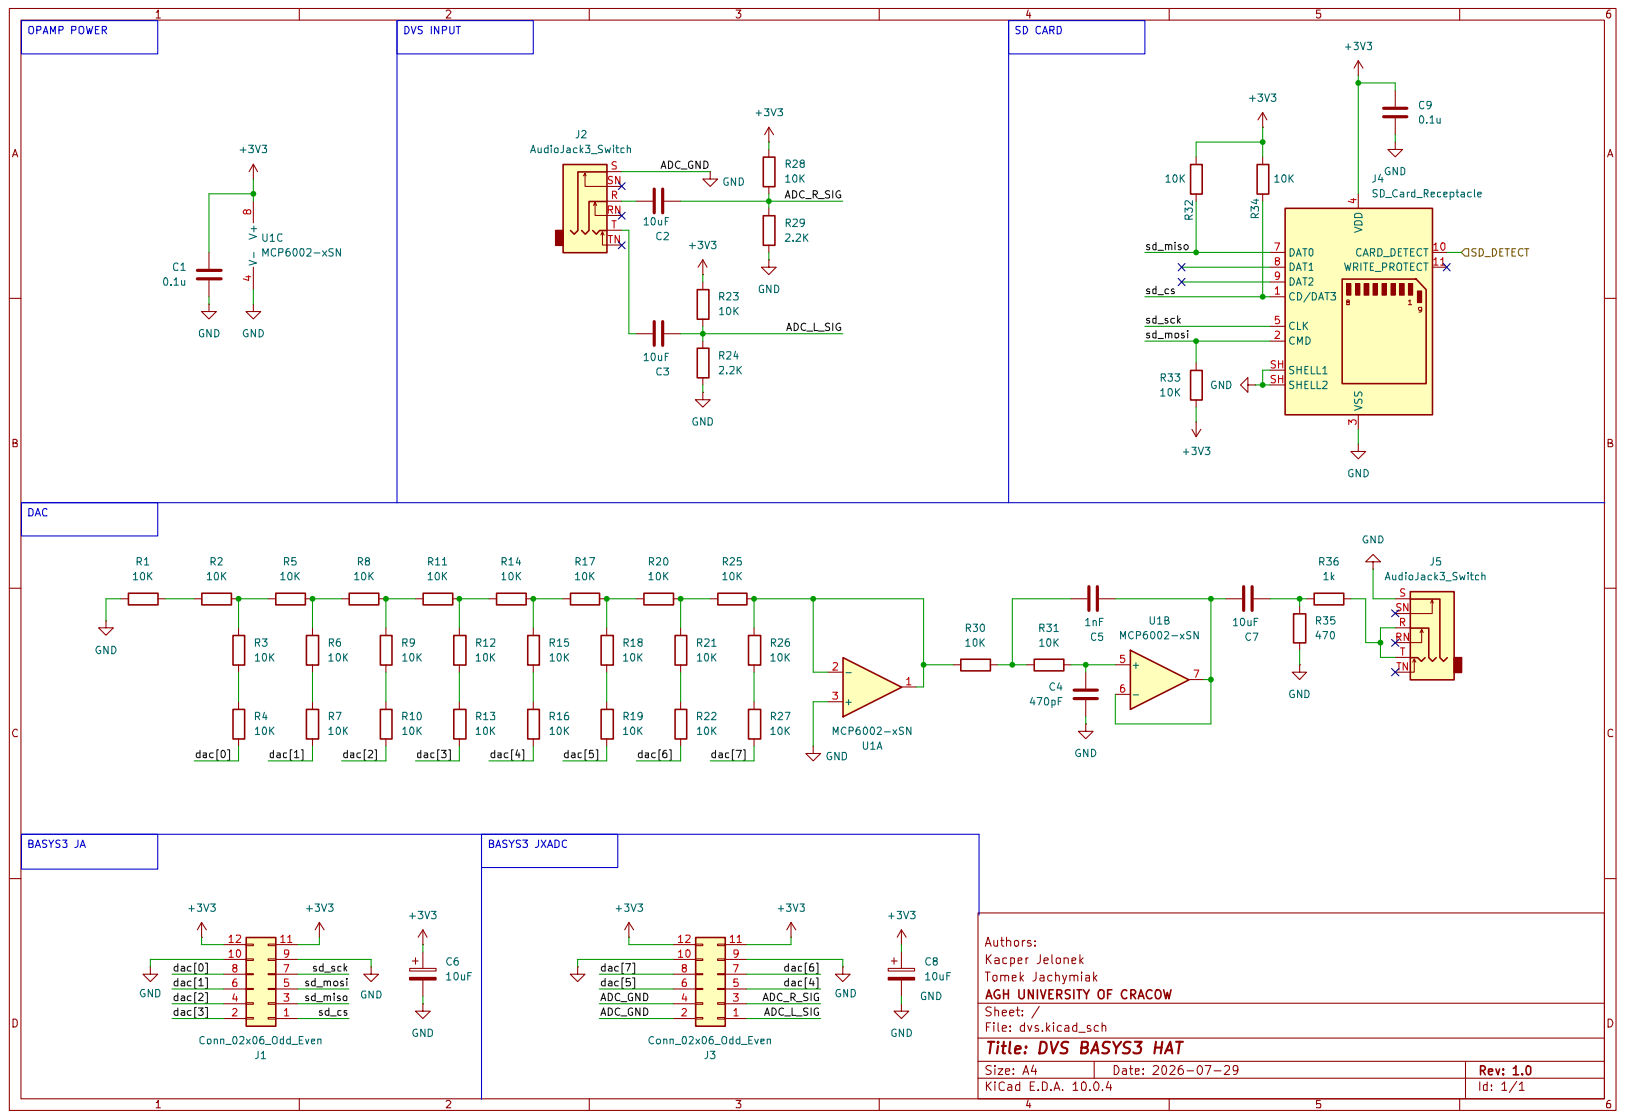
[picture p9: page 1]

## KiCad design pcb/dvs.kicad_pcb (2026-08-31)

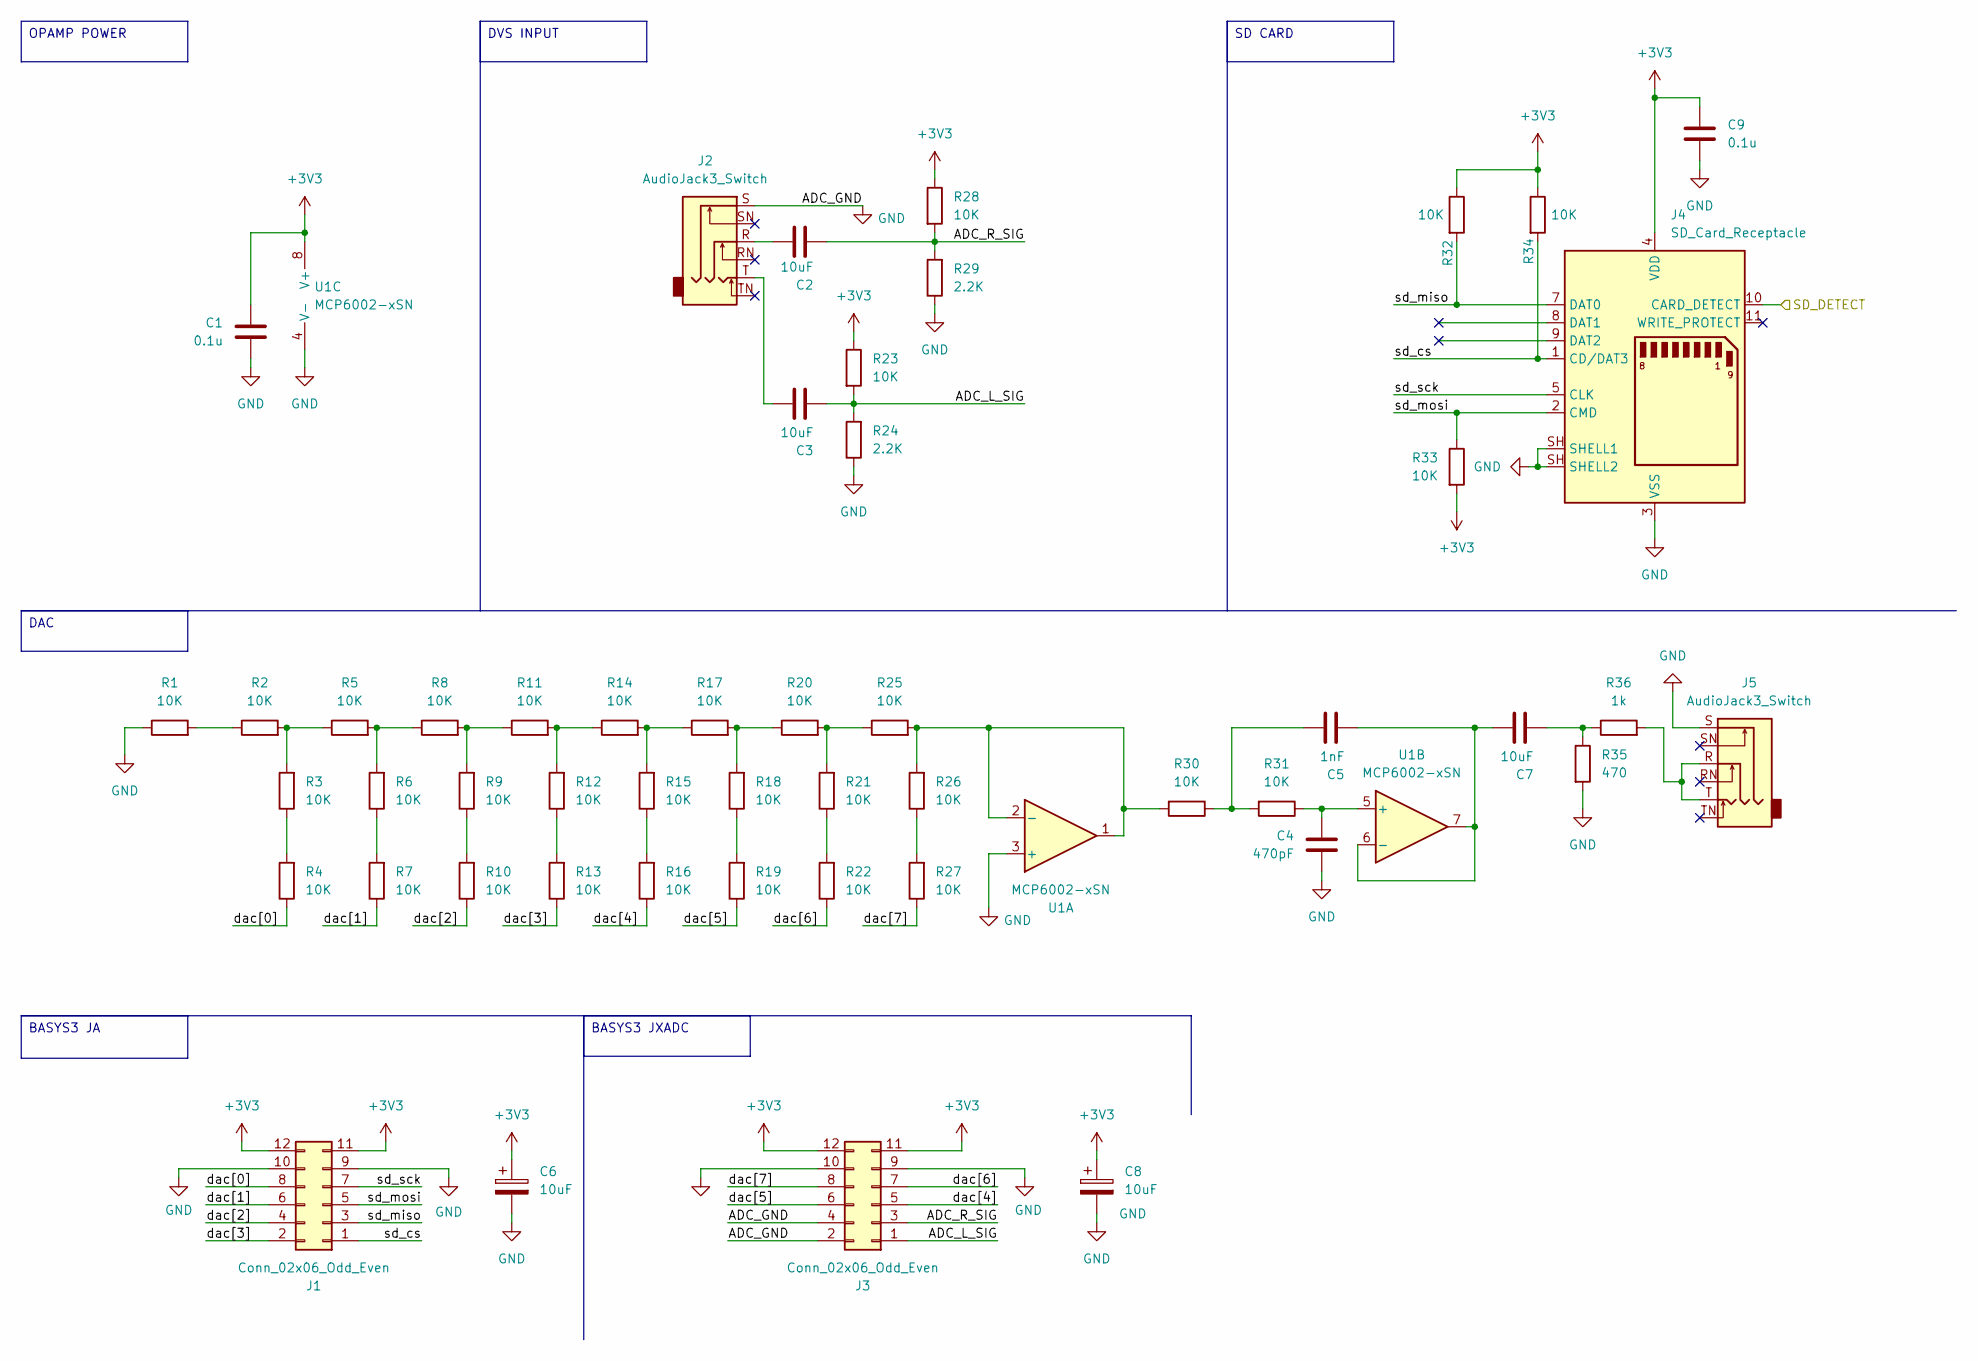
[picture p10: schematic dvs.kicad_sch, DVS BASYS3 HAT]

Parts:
C1, C9: 0.1u; C_0603_1608Metric
C2, C3, C7: 10uF; C_0603_1608Metric
C4: 470pF; C_0603_1608Metric
C5: 1nF; C_0603_1608Metric
C6, C8: 10uF; CP_Elec_6.3x5.4
J1, J3: Conn_02x06_Odd_Even; PinSocket_2x06_P2.54mm_Vertical
J2, J5: AudioJack3_Switch; Jack_6.35mm_Neutrik_NMJ6HFD2-AU_Horizontal
J4: SD_Card_Receptacle; SD_Kyocera_145638009511859+
R1, R2, R3, R4, R5, R6, R7, R8, R9, R10, R11, R12, R13, R14, R15, R16, R17, R18, R19, R20, R21, R22, R23, R25, R26, R27, R28, R30, R31, R32, R33, R34: 10K; R_0603_1608Metric
R24, R29: 2.2K; R_0603_1608Metric
R35: 470; R_0603_1608Metric
R36: 1k; R_0603_1608Metric
U1: MCP6002-xSN; MSOP-8_3x3mm_P0.65mm

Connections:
+3V3: C1.1, C6.1, C8.1, C9.1, J1.11, J1.12, J3.11, J3.12, J4.4 (VDD), R23.1, R28.1, R32.1, R33.2, R34.1, U1.8 (V+)
/ADC_L_SIG: C3.2, J3.1, R23.2, R24.2
/ADC_R_SIG: C2.2, J3.3, R28.2, R29.2
/SD_DETECT: J4.10 (CARD_DETECT)
/dac[0]: J1.8, R4.1
/dac[1]: J1.6, R7.1
/dac[2]: J1.4, R10.1
/dac[3]: J1.2, R13.1
/dac[4]: J3.5, R16.1
/dac[5]: J3.6, R19.1
/dac[6]: J3.7, R22.1
/dac[7]: J3.8, R27.1
/sd_cs: J1.1, J4.1 (CD/DAT3), R34.2
/sd_miso: J1.3, J4.7 (DAT0), R32.2
/sd_mosi: J1.5, J4.2 (CMD), R33.1
/sd_sck: J1.7, J4.5 (CLK)
GND: C1.2, C4.2, C6.2, C8.2, C9.2, J1.9, J1.10, J2.S, J3.2, J3.4, J3.9, J3.10, J4.3 (VSS), J4.6 (VSS), J4.SH (SHELL1), J5.S, R1.1, R24.1, R29.1, R35.2, U1.3 (+), U1.4 (V-)
unnamed: C2.1, J2.R
unnamed: C3.1, J2.T
unnamed: C5.1, R30.1, R31.2
unnamed: C7.2, R35.1, R36.1
unnamed: J5.R, J5.T, R36.2
unnamed: R1.2, R2.1
unnamed: R2.2, R3.2, R5.1
unnamed: R3.1, R4.2
unnamed: R5.2, R6.2, R8.1
unnamed: R6.1, R7.2
unnamed: R9.1, R10.2
unnamed: R8.2, R9.2, R11.1
unnamed: R11.2, R12.2, R14.1
unnamed: R12.1, R13.2
unnamed: R14.2, R15.2, R17.1
unnamed: R15.1, R16.2
unnamed: R17.2, R18.2, R20.1
unnamed: R18.1, R19.2
unnamed: R20.2, R21.2, R25.1
unnamed: R21.1, R22.2
unnamed: R26.1, R27.2
unnamed: R25.2, R26.2, R30.2, U1.1, U1.2 (-)
unnamed: C4.1, R31.1, U1.5 (+)
unnamed: C5.2, C7.1, U1.6 (-), U1.7

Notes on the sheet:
DAC
BASYS3 JA
DVS INPUT
BASYS3 JXADC
OPAMP POWER
SD CARD

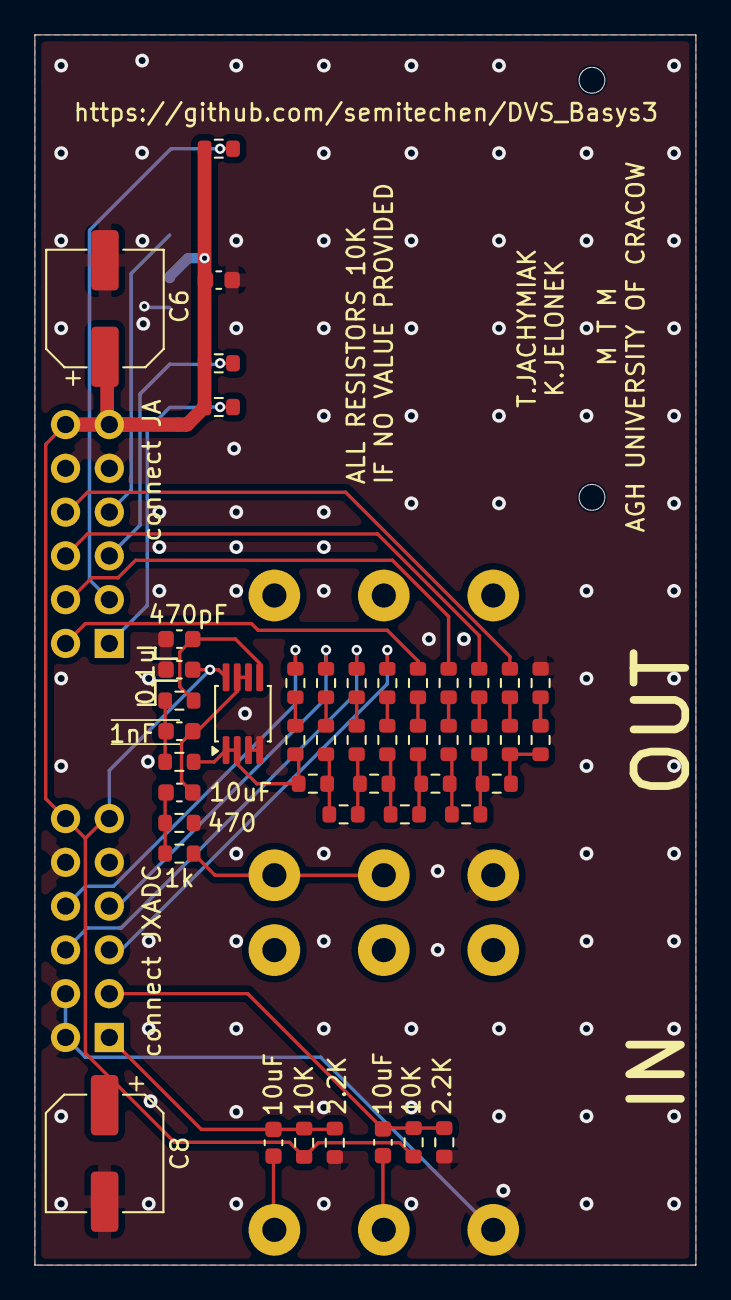
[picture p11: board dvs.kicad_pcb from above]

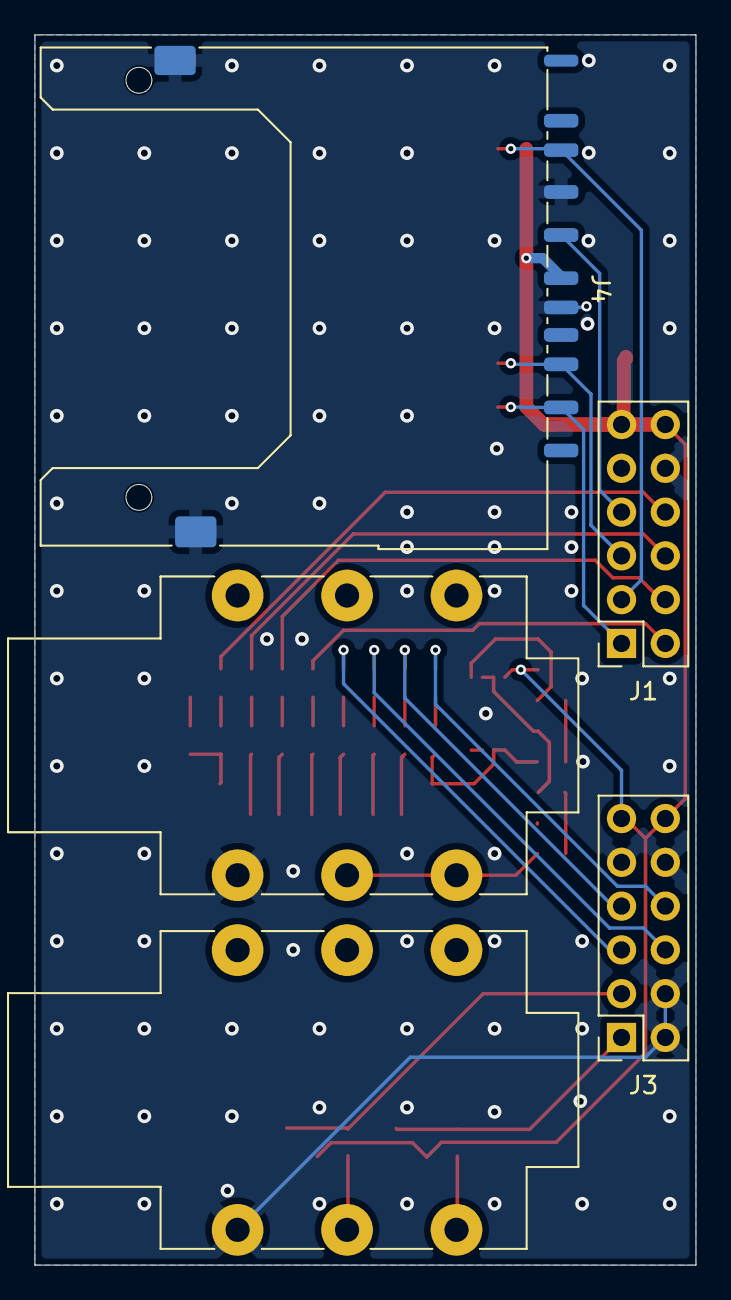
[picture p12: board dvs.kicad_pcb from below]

Board: 2 copper layers, 38.4 x 71.4 mm, 51 parts (5 on the bottom side), 40 nets.

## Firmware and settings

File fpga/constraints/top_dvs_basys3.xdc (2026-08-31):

## This file is a general .xdc for the Basys3 rev B board
## Configured for Dual-Board DVS Architecture (Board A Streamer / Board B DAC Receiver)

## Clock signal
set_property PACKAGE_PIN W5 [get_ports clk]
	set_property IOSTANDARD LVCMOS33 [get_ports clk]
	create_clock -add -name sys_clk_pin -period 10.00 -waveform {0 5} [get_ports clk]

## Switches
set_property PACKAGE_PIN V17 [get_ports {sw[0]}]
	set_property IOSTANDARD LVCMOS33 [get_ports {sw[0]}]

## LEDs
set_property PACKAGE_PIN U16 [get_ports {led[0]}]
	set_property IOSTANDARD LVCMOS33 [get_ports {led[0]}]
set_property PACKAGE_PIN E19 [get_ports {led[1]}]
	set_property IOSTANDARD LVCMOS33 [get_ports {led[1]}]
set_property PACKAGE_PIN U19 [get_ports {led[2]}]
	set_property IOSTANDARD LVCMOS33 [get_ports {led[2]}]
set_property PACKAGE_PIN V19 [get_ports {led[3]}]
	set_property IOSTANDARD LVCMOS33 [get_ports {led[3]}]
set_property PACKAGE_PIN W18 [get_ports {led[4]}]
	set_property IOSTANDARD LVCMOS33 [get_ports {led[4]}]
set_property PACKAGE_PIN U15 [get_ports {led[5]}]
	set_property IOSTANDARD LVCMOS33 [get_ports {led[5]}]
set_property PACKAGE_PIN U14 [get_ports {led[6]}]
	set_property IOSTANDARD LVCMOS33 [get_ports {led[6]}]
set_property PACKAGE_PIN V14 [get_ports {led[7]}]
	set_property IOSTANDARD LVCMOS33 [get_ports {led[7]}]
set_property PACKAGE_PIN V13 [get_ports {led[8]}]
	set_property IOSTANDARD LVCMOS33 [get_ports {led[8]}]
set_property PACKAGE_PIN V3 [get_ports {led[9]}]
	set_property IOSTANDARD LVCMOS33 [get_ports {led[9]}]
set_property PACKAGE_PIN W3 [get_ports {led[10]}]
	set_property IOSTANDARD LVCMOS33 [get_ports {led[10]}]
set_property PACKAGE_PIN U3 [get_ports {led[11]}]
	set_property IOSTANDARD LVCMOS33 [get_ports {led[11]}]
set_property PACKAGE_PIN P3 [get_ports {led[12]}]
	set_property IOSTANDARD LVCMOS33 [get_ports {led[12]}]
set_property PACKAGE_PIN N3 [get_ports {led[13]}]
	set_property IOSTANDARD LVCMOS33 [get_ports {led[13]}]
set_property PACKAGE_PIN P1 [get_ports {led[14]}]
	set_property IOSTANDARD LVCMOS33 [get_ports {led[14]}]
set_property PACKAGE_PIN L1 [get_ports {led[15]}]
	set_property IOSTANDARD LVCMOS33 [get_ports {led[15]}]

## Buttons
set_property PACKAGE_PIN U18 [get_ports rst]  
    set_property IOSTANDARD LVCMOS33 [get_ports rst]
set_property PACKAGE_PIN T18 [get_ports btn_up]
    set_property IOSTANDARD LVCMOS33 [get_ports btn_up]
set_property PACKAGE_PIN U17 [get_ports btn_down]
    set_property IOSTANDARD LVCMOS33 [get_ports btn_down]

## Pmod Header JA (Karta SD + DAC bity 0-3)
## Sch name = JA1 (Górny rząd, pin 1) - SD CS
set_property PACKAGE_PIN J1 [get_ports {sd_cs}]
set_property IOSTANDARD LVCMOS33 [get_ports {sd_cs}]

## Sch name = JA2 (Górny rząd, pin 2) - SD MISO
set_property PACKAGE_PIN L2 [get_ports {sd_miso}]
set_property IOSTANDARD LVCMOS33 [get_ports {sd_miso}]
set_property PULLUP true [get_ports {sd_miso}]

## Sch name = JA3 (Górny rząd, pin 3) - SD MOSI
set_property PACKAGE_PIN J2 [get_ports {sd_mosi}]
set_property IOSTANDARD LVCMOS33 [get_ports {sd_mosi}]

## Sch name = JA4 (Górny rząd, pin 4) - SD SCK
set_property PACKAGE_PIN G2 [get_ports {sd_sck}]
set_property IOSTANDARD LVCMOS33 [get_ports {sd_sck}]

## Sch name = JA7 (Dolny rząd, pin 1) - DAC Bit 3
set_property PACKAGE_PIN H1 [get_ports {dac[3]}]
set_property IOSTANDARD LVCMOS33 [get_ports {dac[3]}]

## Sch name = JA8 (Dolny rząd, pin 2) - DAC Bit 2
set_property PACKAGE_PIN K2 [get_ports {dac[2]}]
set_property IOSTANDARD LVCMOS33 [get_ports {dac[2]}]

## Sch name = JA9 (Dolny rząd, pin 3) - DAC Bit 1
set_property PACKAGE_PIN H2 [get_ports {dac[1]}]
set_property IOSTANDARD LVCMOS33 [get_ports {dac[1]}]

## Sch name = JA10 (Dolny rząd, pin 4) - DAC Bit 0
set_property PACKAGE_PIN G3 [get_ports {dac[0]}]
set_property IOSTANDARD LVCMOS33 [get_ports {dac[0]}]

## Pmod Header JC (High-Speed UART Link between Board A and Board B)
## Sch name = JC1 (Pin 1)
set_property PACKAGE_PIN K17 [get_ports uart_rx_pin]
set_property IOSTANDARD LVCMOS33 [get_ports uart_rx_pin]
set_property PULLUP true [get_ports uart_rx_pin]

set_property PACKAGE_PIN K17 [get_ports uart_tx_pin]
set_property IOSTANDARD LVCMOS33 [get_ports uart_tx_pin]

## Pmod Header JXADC (XADC Analog Timecode Inputs + DAC bity 4-7)
## Sch name = XA1_P (Left Channel Analog In +)
set_property PACKAGE_PIN J3 [get_ports vauxp6]
    set_property IOSTANDARD LVCMOS33 [get_ports vauxp6]

## Sch name = XA1_N (Left Channel Analog In -)
set_property PACKAGE_PIN K3 [get_ports vauxn6]
    set_property IOSTANDARD LVCMOS33 [get_ports vauxn6]

## Sch name = XA2_P (Right Channel Analog In +)
set_property PACKAGE_PIN L3 [get_ports vauxp14]
	set_property IOSTANDARD LVCMOS33 [get_ports vauxp14]

## Sch name = XA2_N (Right Channel Analog In -)
set_property PACKAGE_PIN M3 [get_ports vauxn14]
	set_property IOSTANDARD LVCMOS33 [get_ports vauxn14]

## Sch name = XA3_P (DAC Bit 4)
set_property PACKAGE_PIN M2 [get_ports {dac[4]}]
set_property IOSTANDARD LVCMOS33 [get_ports {dac[4]}]
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

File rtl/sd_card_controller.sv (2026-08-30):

`timescale 1ns / 1ps

/*
Author: Tomasz Jachymiak
 */

module sd_card_controller (
    input  logic        clk,
    input  logic        rst,
    
    // Interfejs uzytkownika
    input  logic        rd_req,      
    input  logic [31:0] rd_addr,     
    output logic        sd_ready,    
    output logic [7:0]  out_byte,    
    output logic        out_valid,   
    
    output logic        sd_cs,
    output logic        sd_sck,
    output logic        sd_mosi,
    input  logic        sd_miso,

    output logic [3:0]  ctrl_state
);

    logic        spi_start;
    logic [7:0]  spi_data_in;
    logic [15:0] spi_clk_div;
    logic [7:0]  spi_data_out;
    logic        spi_ready;

    spi_master spi_inst (
        .clk(clk),
        .rst(rst),
        .start(spi_start),
        .data_in(spi_data_in),
        .clk_div(spi_clk_div),
        .data_out(spi_data_out),
        .ready(spi_ready),
        .sck(sd_sck),
        .mosi(sd_mosi),
        .miso(sd_miso)
    );

    // DEFINICJE KOMEND SD
    localparam [47:0] CMD0_RESET      = 48'h40_00_00_00_00_95; 
    localparam [47:0] CMD8_SEND_IF    = 48'h48_00_00_01_AA_87; 
    localparam [47:0] CMD55_APP_CMD   = 48'h77_00_00_00_00_01; 
    localparam [47:0] ACMD41_SD_SEND  = 48'h69_40_00_00_00_77; 

    typedef enum logic [3:0] {
        ST_POWER_ON,      
        ST_INIT_CMD0,     
        ST_INIT_CMD8,     
        ST_INIT_CMD55,    
        ST_INIT_ACMD41,   
        ST_INIT_DESELECT, 
        ST_IDLE,          
        ST_READ_CMD17,    
        ST_READ_WAIT_TOK, 
        ST_READ_DATA,     
        ST_READ_CRC       
    } state_t;

    state_t state, state_nxt;
    state_t next_init_state, next_init_state_nxt; 

    logic [3:0]  cmd_byte_idx, cmd_byte_idx_nxt; 
    logic [47:0] current_cmd, current_cmd_nxt;
    logic [7:0]  timeout_cnt, timeout_cnt_nxt;
    logic        sd_cs_reg, sd_cs_nxt;
    logic [9:0]  byte_cnt, byte_cnt_nxt;
    logic        sd_ready_reg, sd_ready_nxt;

    assign sd_cs      = sd_cs_reg;
    assign sd_ready   = sd_ready_reg;
    assign ctrl_state = state;

    always_comb begin
        state_nxt           = state;
        next_init_state_nxt = next_init_state;
        cmd_byte_idx_nxt    = cmd_byte_idx;
        current_cmd_nxt     = current_cmd;
        timeout_cnt_nxt     = timeout_cnt;
        sd_cs_nxt           = sd_cs_reg;
        sd_ready_nxt        = sd_ready_reg;
        byte_cnt_nxt        = byte_cnt;
        
        spi_start           = 1'b0;
        spi_data_in         = 8'hFF;
        spi_clk_div         = (state >= ST_IDLE) ? 16'd2 : 16'd250; 
        out_valid           = 1'b0;
        out_byte            = 8'h00;

        case (state)
            ST_POWER_ON: begin
                sd_cs_nxt = 1'b1;
                sd_ready_nxt = 1'b0;
                
                if (spi_ready) begin
                    if (timeout_cnt < 10) begin
                        spi_start = 1'b1;
                        spi_data_in = 8'hFF;
                        timeout_cnt_nxt = timeout_cnt + 1;
                    end else begin
                        state_nxt = ST_INIT_CMD0;
                        timeout_cnt_nxt = '0;
                        cmd_byte_idx_nxt = '0;
                        current_cmd_nxt = CMD0_RESET; 
                    end
                end
            end

            ST_INIT_CMD0: begin
                if (spi_ready) begin
                    sd_cs_nxt = 1'b0; 
                    if (cmd_byte_idx < 6) begin
                        spi_start = 1'b1;
                        spi_data_in = current_cmd[47-:8]; 
                        current_cmd_nxt = {current_cmd[39:0], 8'h00}; 
                        cmd_byte_idx_nxt = cmd_byte_idx + 1;
                    end else begin
                        spi_start = 1'b1;
                        spi_data_in = 8'hFF;
                        
                        if (spi_data_out[7] == 1'b0) begin 
                            state_nxt = ST_INIT_DESELECT; 
                            next_init_state_nxt = ST_INIT_CMD8; 
                            cmd_byte_idx_nxt = '0;
                            timeout_cnt_nxt = '0;
                            sd_cs_nxt = 1'b1; 
                            current_cmd_nxt = CMD8_SEND_IF; 
                        end else begin
                            if (timeout_cnt < 8'd16) begin
                                timeout_cnt_nxt = timeout_cnt + 1;
                            end else begin
                                // Karta zignorowala komende - Agresywny reset cyklu
                                cmd_byte_idx_nxt = '0;
                                timeout_cnt_nxt = '0;
                                current_cmd_nxt = CMD0_RESET;
                                sd_cs_nxt = 1'b1; 
                            end
                        end
                    end
                end
            end
            
            ST_INIT_CMD8: begin
                if (spi_ready) begin
                    sd_cs_nxt = 1'b0; 
                    if (cmd_byte_idx < 6) begin
                        spi_start = 1'b1;
                        spi_data_in = current_cmd[47-:8]; 
                        current_cmd_nxt = {current_cmd[39:0], 8'h00};
                        cmd_byte_idx_nxt = cmd_byte_idx + 1;
                    end else if (cmd_byte_idx == 6) begin
                        spi_start = 1'b1;
                        spi_data_in = 8'hFF;
                        if (spi_data_out[7] == 1'b0) begin 
                            cmd_byte_idx_nxt = 7;
                            timeout_cnt_nxt = '0;
                        end else begin
                            if (timeout_cnt < 8'd32) begin
                                timeout_cnt_nxt = timeout_cnt + 1;
                            end else begin
                                // Brak R7 / stara karta - pomijamy bledy i idziemy dalej
                                state_nxt = ST_INIT_DESELECT; 
                                next_init_state_nxt = ST_INIT_CMD55; 
                                cmd_byte_idx_nxt = '0;
                                timeout_cnt_nxt = '0;
                                sd_cs_nxt = 1'b1; 
                                current_cmd_nxt = CMD55_APP_CMD;
                            end
                        end
                    end else begin
                        spi_start = 1'b1;
                        spi_data_in = 8'hFF;
                        cmd_byte_idx_nxt = cmd_byte_idx + 1;
                        
                        if (cmd_byte_idx == 10) begin
                            state_nxt = ST_INIT_DESELECT; 
                            next_init_state_nxt = ST_INIT_CMD55; 
                            cmd_byte_idx_nxt = '0;
                            sd_cs_nxt = 1'b1; 
                            current_cmd_nxt = CMD55_APP_CMD; 
                        end
                    end
                end
            end
            
            ST_INIT_CMD55: begin
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

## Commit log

2026-05-18 Add WAV to PCM converter script and generated track LUT. Closes #21
2026-05-20 Implement SPI Master and FSM testbench. Closes #5, Closes #22.
2026-05-29 test: XADC and UART verification for analog signal testing Closes #16
2026-05-29 chore: Cleanup verification logic and finalize XADC integration for main merge
    [adc_test.csv]
2026-06-01 feat(sd_card): implement SPI master, initialization FSM, and block read. Resolves #6, Resolves #7
    [sd_card_controller.sv, sd_card_controller_tb.sv]
2026-06-10 feat(xadc,vga): integrate XADC data acquisition and advanced VGA graphics
    This commit merges the jxadc branch into main, integrating the XADC interface for analog signal acquisition and the VGA display subsystem with mouse interaction and ROM-based graphics.
    Closes #9, Closes #10, Closes #16
    [adc_test.csv]
2026-06-11 feat: dc blocking and low pass filter implementation Closes #11
2026-07-30 chore: gitignore for KICAD
2026-07-30 feat: initail pcb board kicad project
    [dvs.kicad_pcb, dvs.kicad_sch]
2026-08-13 fix: cleanup constraints and TCL script to allow bitstream generation
    [sd_card_controller.sv, sd_card_controller_tb.sv, top_dvs_basys3.xdc]
2026-08-13 test(audio): add Serato 12in 33RPM timecode audio test signal for Reloop RP-7000 MK2 line level output
2026-08-14 test(adc): add timecode position tracking test and 250ms LED sync verification
2026-08-14 feat(adc): implement production relative mode timecode tracking engine
2026-08-16 refactor(dvs): decouple 16-LED display architecture from core timecode engine
2026-08-16 fix(dvs): resolve 32-bit DC estimator arithmetic overflow and squelch envelope saturation
    [timecode_pos_tracker.sv]
2026-08-16 chore: clean up test audio files, scripts, and finalize production DVS implementation
    [adc_test.csv]
2026-08-24 Fix #23: Extract button debouncer to a separate module and resolve DVT missing port warning
    [sd_card_controller.sv, sd_card_controller_tb.sv]
2026-08-24 Fix #19: Implement track selector, update audio converter and map button pins
    [top_dvs_basys3.xdc]
2026-08-24 Fix #20: Map Basys3 LEDs to system diagnostic signals for SD and buffer status
2026-08-30 Refactor: Split architecture and implement Board B (Audio Engine) with NCO and UART RX
2026-08-30 feat(player): integrate high-fidelity R-2R DAC and optimize Board B audio pipeline
    - Integrate 16x oversampled R-2R DAC engine (rtl/r2r_dac.sv) with 1st-order unconditionally stable noise shaping, TPDF dither, digital headroom scaling, and IOB registered outputs.
    - Fix 32-bit integer arithmetic overflow in rtl/variable_speed_player.sv, restoring exact 44.1 kHz full playback speed and aligning BRAM read latency.
    - Accelerate SD card SPI read clock in rtl/sd_card_controller.sv to 16.67 MHz during sector transfers, eliminating FIFO buffer starvation.
    - Implement auto-start playback and play request latching in rtl/sd_bram_bridge.sv.
    - Add 50 ms watchdog fallback and internal pull-up on uart_rx_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
    [sd_card_controller.sv, top_dvs_basys3.xdc]
2026-08-30 feat(dvs): implement real-time timecode speed estimation and smart vinyl arbitration
    - Enhance rtl/timecode_pos_tracker.sv with high-sensitivity Schmitt trigger and envelope squelch gate.
    - Add real-time Q4.12 playback speed estimator with 1st-order IIR low-pass filtering and 25 ms stop timeout.
    - Implement smart DVS mode arbitration in rtl/top_dvs_basys3.sv with automatic vinyl pickup detection.
    - Configure real-time LED diagnostics and 12-LED spinning platter visualizer.
2026-08-31 feat(rtl): implement dual-board DVS architecture with 2 Mbps UART audio streaming
    - Add top_board_a_streamer module integrating XADC timecode decoding, SD card reader, NCO player, and UART TX.
    - Add top_board_b_dac module with UART RX, 16x noise-shaped R-2R DAC, and 12-LED VU meter.
    - Add sample_valid strobe to variable_speed_player for synchronized UART transmission.
2026-08-31 feat(hw): add QSPI non-volatile flash configuration and multi-board build/programming scripts
    - Configure XDC bitstream properties for Artix-7 Master QSPI boot (SPI_BUSWIDTH 4, CONFIGRATE 33, COMPRESS TRUE).
    - Update remote_build.sh to support independent Board A and Board B synthesis targets and .bin extraction.
    - Update program_fpga.sh with multi-device FTDI selection and persistent Flash writing (-f).
    - Update project_details.tcl and generate_bitstream.tcl for dual-board design sources.
2026-08-31 docs: update project documentation for dual-board DVS architecture, wiring, and QSPI boot
    - Document system block diagram and module breakdown for Board A (Streamer) and Board B (DAC).
    - Provide detailed physical wiring guide between boards, turntable JXADC conditioning, and DAC pins.
    - Add instructions for remote build workflow, audio formatting, and persistent QSPI Flash programming.
2026-08-31 fix(constraints): add dedicated XDC files per top module to achieve 0 critical warnings
    - Add fpga/constraints/top_board_a_streamer.xdc mapping only Board A ports and QSPI boot properties.
    - Add fpga/constraints/top_board_b_dac.xdc mapping only Board B DAC/UART ports and QSPI boot properties.
    - Update generate_bitstream.tcl to dynamically load matching constraints per target.
    [timecode_pos_tracker.sv, top_board_a_streamer.xdc, top_board_b_dac.xdc]
2026-08-31 feat(pcb): integrate KiCad schematic and PCB layout with audio jack ground fix
    - Update pcb/dvs.kicad_sch connecting audio jack sleeve pad to GND.
    - Update pcb/dvs.kicad_pcb with updated ground plane routing and trace clearance.
    [dvs.kicad_pcb, dvs.kicad_sch]
2026-09-01 refactor: clean up legacy template files, obsolete modules, and update project details
    - Remove unused legacy VGA/mouse template files and early prototype RTL modules.
    - Remove obsolete testbenches and keep active DVS simulation suite.
    - Update project_details.tcl and .gitignore to track QSPI Flash .bin artifacts.
    [adc_test.csv]
2026-09-01 docs: add comprehensive English documentation with video and hardware gallery
    - Create professional, in-depth English README.md with system architecture diagrams, DSP algorithms, and hardware guides.
    - Embed YouTube demonstration video link and preview banner.
    - Add hardware photos, KiCad schematics, and PCB layout captures in pictures/ directory.

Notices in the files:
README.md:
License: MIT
